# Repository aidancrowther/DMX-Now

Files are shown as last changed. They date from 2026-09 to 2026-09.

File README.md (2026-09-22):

# DMX Now

DMX Now is an ESP8266-based DMX512 system. A host daemon accepts DMX from
Art-Net or an ENTTEC-compatible serial client, sends the latest complete
universe to a wireless transmitter, and distributes it over QuickESPNow to any
number of battery-powered receivers. Each receiver regenerates DMX512 through
an RS-485 transceiver.

```text
Lighting software -> host daemon -> ESP8266 transmitter
                                      |
                                      +-- QuickESPNow --> one or more receivers
                                                           |
                                                           +--> DMX512 fixtures
```

## Supported operating modes

The project supports the following operating modes and hardware roles.

### 1. Host bridge mode — normal production operation

The Linux host daemon accepts a DMX universe from one of its configured inputs,
the integrated ESP8266 transmitter broadcasts it over QuickESPNow, and one or
more ESP8266 receivers regenerate DMX512 for fixtures.

```text
Host input -> Linux daemon -> ESP8266 transmitter
                              |
                              +-- QuickESPNow -> ESP8266 receiver(s) -> DMX512
```

The validated native/integrated transmitter target is 20 Hz:

```text
Wireless refresh:   20 Hz
Host transmitter:   115200 baud, 8N2
Universe:            512 channels
Wireless transport: QuickESPNow / ESP-NOW
Receiver output:    DMX512, 250000 baud, 8N2
```

The host can receive DMX through an ENTTEC-compatible serial PTY, Art-Net
ArtDMX, or an optional raw-DMX virtual PTY. The daemon also provides the
terminal dashboard, receiver management, priority traffic, channel gates, and
fail-safe configuration.

### 2. Management-only mode

The daemon and integrated transmitter can run without emitting ordinary DMX.
This mode is intended for a deployment where another device owns normal DMX,
especially the standalone physical-DMX retransmitter below. Telemetry,
receiver discovery, fail-safe settings, output control, locate, channel gates,
and explicit priority traffic remain available.

Start the daemon with either:

```bash
wireless-dmx run --management-only --config configs/config.example.toml
# or set [daemon] mode = "management_only" in the configuration
```

The integrated transmitter can also be built as a locked management-only image
with `./Helpers/flash_transmitter.sh --lock-management-only`.

In management-only mode, the transmitter passively listens for the standalone
retransmitter's ordinary ESP-NOW fragments and periodically reports the latest
complete universe to the daemon. The dashboard displays this read-only,
best-effort observed universe for operator feedback; it is not required for
retransmission or receiver operation. The transmitter keeps a local fallback for
its own priority transmissions because it cannot receive its own broadcast. When
a channel is changed to `LOCKED`, its current observed value is captured and
later retransmitter updates cannot replace it.

### 3. Standalone physical-DMX retransmitter

The standalone ESP8266 retransmitter receives physical DMX through a
receive-only RS-485 interface on UART0/GPIO3 and broadcasts the existing normal
three-fragment wireless protocol directly to the receivers. It does not require
the Linux daemon, a host transmitter, or a management transmitter for normal
operation.

Its production target is 10 Hz. It accepts complete and supported partial
physical-DMX frames from 24 through 512 slots, zero-filling the remaining
channels through channel 512. The retransmitter never drives its physical DMX
input line and has diagnostics disabled in the production image.

```text
Physical DMX source -> receive-only RS-485 -> ESP8266 retransmitter
                                               |
                                               +-- ESP-NOW -> receiver(s) -> fixtures
```

See [`Docs/retransmitter-deployment.md`](Docs/retransmitter-deployment.md) for
wiring, production flashing, radio configuration, recovery, and validation.

The retransmitter's production GPIO allocation keeps GPIO2 assigned to the
locate indicator (`LED_BUILTIN`). DMX input is receive-only and is not remotely
gated through GPIO2. Optional battery monitoring uses GPIO1 while DMXUART runs
in `SERIAL_RX_ONLY` mode. The production image with battery monitoring enabled
is built and flashed with:

```bash
./Helpers/flash_retransmitter.sh --production --battery-monitor -f \
  --port <RETRANSMITTER_PROGRAMMER_PORT>
```

### 4. Monitored retransmitter deployment

The retransmitter can be paired with a separate locked management-only ESP8266
transmitter. The physical retransmitter remains the sole normal-DMX authority;
the management transmitter provides receiver telemetry and control only. This
mode supports remote fail-safe configuration, receiver output control, locate,
channel gates, and explicit priority operations without creating a competing
ordinary-DMX source.

### 5. Arduino Mega USB-controlled DMX controller using `DMXSerial`

`Tests/mega_dmx_controller/` provides a simple local DMX source for bench
testing. It uses the `DMXSerial` library on Mega USART1, with DMX output on pin
18 and the USB connection available on `/dev/ttyUSB1` at 115200 baud, 8N1.

Flash it with:

```bash
./Helpers/flash_mega_dmx_controller.sh -f --port /dev/ttyUSB1
```

Enter newline-terminated commands over USB:

```text
<channel 1-512> <value 0-255>
1 255
24 128
clear
status
help
```

### 6. Arduino Mega USB-controlled DMX controller using `DmxSimple`

`Tests/mega_dmxsimple_controller/` is the equivalent local controller using
the `DmxSimple` library. Unlike the `DMXSerial` variant, it outputs DMX through
Mega digital pin 3 and does not use USART1. The USB command interface is still
available at 115200 baud, 8N1.

Flash it with:

```bash
./Helpers/flash_mega_dmxsimple_controller.sh -f --port /dev/ttyUSB1
```

It accepts the same `channel value`, `clear`, `status`, and `help` commands.

### Wireless transport behavior

The wireless transport is latest-state based. A receiver retains its last
complete universe when a fragment or wireless update is missed; incomplete
universes are discarded rather than promoted. The retransmitter and native
transmitter use the same shared packet protocol.

## Functions

- Receives DMX through ENTTEC-compatible serial input, Art-Net ArtDMX, or an
  optional raw-DMX virtual serial input accepting complete 512-byte universes.
- Expires incomplete raw-DMX bursts after 1 second without changing the active
  universe.
- Paces native/integrated wireless transmission at the validated 20 Hz rate and
  standalone retransmission at the validated 10 Hz rate.
- Reconstructs fragmented 512-channel universes safely on receivers using
  staging and active buffers; incomplete data is never promoted.
- Retains the last complete universe through temporary wireless loss and
  automatically recovers when a new valid universe arrives.
- Reports receiver telemetry including link freshness, battery, RSSI, sequence,
  counters, firmware, and fail-safe state.
- Delivers targeted priority complete universes with bounded retries and ACKs.
- Supports runtime channel gates: `OPEN`, `MANAGEMENT_ONLY`, and `LOCKED`.
- Supports receiver fail-safe modes:
  - `hold`: retain the last complete universe;
  - `blackout`: output a zero universe after the timeout;
  - `disable_line`: disable the RS-485 driver after the timeout.
- Provides receiver output enable/disable control and a temporary locate function
  for identifying hardware.
- Provides persistent receiver friendly names in the host configuration.
- Provides a Linux PTY input path and terminal dashboard with manual universe
  editing, normal/priority transmission, channel gates, receiver selection,
  output control, locate, telemetry, and validation actions.
- In management-only mode, optionally displays a best-effort observed universe
  reconstructed by the management transmitter from the standalone retransmitter;
  this is read-only QoL telemetry and is not required for operation.
- Converts physical DMX to the normal wireless protocol in standalone
  retransmitter mode, including partial-frame zero-fill through channel 512.
- Provides two simple Mega bench controllers that set individual channels over
  USB and continuously transmit a 512-channel DMX universe.

## Repository layout

```text
Firmware/Receiver/                  ESP8266 receiver firmware
Firmware/Transmitter/               ESP8266 transmitter firmware
Firmware/ReTransmitter/             UART0 physical DMX -> normal ESP-NOW firmware
Libraries/                           pinned project and third-party libraries
Host Software/wireless_dmx_daemon/   Linux/macOS host daemon and tests
Tests/                               firmware and hardware monitor sketches
Helpers/                             compile/flash helpers
Docs/                                detailed architecture, protocol, and validation docs
Hardware/                            PCB, schematic, enclosure, and manufacturing assets
DEVELOPMENT_PROGRESS.md   development history and status
```

## Hardware

Each receiver uses an ESP-01/ESP8266, MAX3485 RS-485 transceiver, battery
power/charging circuitry, and an external low-battery comparator. The receiver
uses GPIO1 for DMX TX, GPIO2 for inverted MAX3485 driver enable, and GPIO3 for
the active-high low-battery signal. See `Docs/hardware.md` and the schematic in
`Hardware/PCB Files/1-Schematic_ESP DMX.json`.

## Bundled libraries and pinned versions

DMX Now ships with the following bundled libraries. Use these project copies for
reproducible builds rather than substituting similarly named Arduino Library
Manager packages.

| Library | Role | Upstream | Declared version | Exact project pin |
|---|---|---|---:|---|
| [QuickESPNow fork](https://github.com/aidancrowther/QuickESPNow) ([upstream](https://github.com/gmag11/QuickESPNow)) | ESP-NOW transport | `Libraries/QuickESPNow/` | `0.8.1` | `27f88ad99e4b58958934c3a3dfabd62ccd338c62` |
| [espDMX fork](https://github.com/aidancrowther/espDMX) ([upstream](https://github.com/mtongnz/espDMX)) | ESP8266 physical DMX output | `Libraries/espDMX/` | v2 | `608ce009edfeebc3bca44b184a9dc667de055284` |
| [DMXUART](https://github.com/casesolved-co-uk/DMXUART) | Physical-DMX UART input/output | `Libraries/DMXUART/` | `4.0.3` | Bundled project copy |
| WirelessDMX | Project-owned wireless/management protocol | `Libraries/WirelessDMX/` | `1.0.0` | Matching DMX Now source |

For now, the DMX Now build points at the `aidancrowther` forks of QuickESPNow
and espDMX so the local changes remain available for pull requests and long-term
preservation. The original maintainer repositories are retained as upstream
references. QuickESPNow includes three project-specific commits beyond upstream,
and espDMX includes one. The exact commit pins above are authoritative.
QuickESPNow is MIT licensed, espDMX is GPL-3.0, and DMXUART is MIT licensed;
complete license texts are retained beside the bundled sources. `LXESP8266DMX`
was an unused former dependency and has been intentionally removed.

## Build and flash

The project uses `arduino-cli`, not PlatformIO:

```bash
./Helpers/flash_transmitter.sh
./Helpers/flash_receiver.sh
./Helpers/flash_retransmitter.sh
```

The normal transmitter helper defaults to bridge mode. Build the optional
management-only role with `./Helpers/flash_transmitter.sh --management-only`.
The daemon defaults to bridge mode; use `[daemon] mode = "management_only"` or
`wireless-dmx run --management-only` for management-only operation. The
management role never emits ordinary DMX, but priority/gate transactions remain
available.

The manual editor remains available in management-only mode and sends priority
traffic. Management edits may explicitly change locked channels. A lock only
blocks ordinary source/retransmitter updates; entering a lock captures the value
currently shown by the observer. Use the manual editor's `l` key to cycle gates.

Add `-f --port <device>` to flash a selected board. The helpers support
`--define` for compile-time test settings. Never leave a test-only transmitter
or receiver define enabled in a production image.

For physical retransmitter wiring, deployment roles, optional management-only
monitoring, and production/test image recovery, see
[`Docs/retransmitter-deployment.md`](Docs/retransmitter-deployment.md).

The reflashed production retransmitter was smoke-tested with a live Mega DMX
source and diagnostic receiver: 356 valid normal-DMX records were observed,
sequences advanced from 12 through 370, retransmitter input frames increased
from 0 to 253, wireless frames increased from 0 to 252, and wireless send
failures remained at 0.

## Host daemon

```bash
cd "Host Software/wireless_dmx_daemon"
python3 -m pip install .
wireless-dmx run --config configs/config.example.toml
```

The daemon prints the Linux PTY path. Configure a serial-capable application to
use that path, or use Art-Net Universe 0 over UDP port 6454. The complete daemon
configuration is documented in `Docs/daemon.md` and demonstrated in
`Host Software/wireless_dmx_daemon/configs/config.example.toml`.

Dashboard configurations are stored under `Host Software/wireless_dmx_daemon/configs/`. The
dashboard can select a configuration interactively when launched without
`--config`. The CLI and scripted dashboard forms continue to accept
`--config <path>`.

The optional raw-DMX input creates a second PTY and accepts one complete
512-byte universe per burst. Configure it under `[raw_virtual_port]` and select
it with `[input] source_policy = "raw_serial"`; incomplete bursts expire after
1 second by default.

## Receiver fail-safe configuration

```toml
[receiver_failsafe]
mode = "hold"          # hold, blackout, or disable_line
timeout_seconds = 60   # validated range: 30..3600
```

Settings are sent at runtime and are not persisted in receiver flash. Receivers
start with compile-time defaults and the daemon reapplies its configured
generation after startup, transmitter reconnect, receiver discovery, or
receiver reboot. Detailed semantics and finite validation procedures are in
`Docs/receiver-failsafe.md`.

## Tests

Run the host suite with:

```bash
cd "Host Software/wireless_dmx_daemon"
python3 -m pytest -q
```

The detailed test catalogue is in `Docs/testing.md`. Hardware-specific results
are kept separately in `Docs/lab-validation.md`; they are evidence for one
validated setup, not a requirement that every deployment have the same number
of receivers, USB paths, or monitor hardware.

The dashboard hotkey reference is in `Docs/daemon.md`.

## Limitations

- The current virtual serial backend targets Linux.
- Applications that only enumerate physical USB DMX interfaces may not list a
  Linux PTY; use Art-Net in that situation.
- Wireless rates above 20 Hz are experimental and not production-validated.
- ESP-NOW is unencrypted in the current QuickESPNow configuration.
- Receiver charging and DMX equipment require the isolation precautions in the
  hardware documentation.

## Project note

This is a vibe-coded project: AI-assisted development was used extensively for
implementation, documentation, and validation support. The hardware design,
wiring, and physical engineering decisions were managed by me.

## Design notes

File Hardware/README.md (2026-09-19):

# Hardware assets

This directory contains the physical design assets for DMX Now receivers and
related hardware.

## Contents

- `3D Models/` — enclosure and mechanical parts used to design and manufacture
  receiver housings. The current models are provided as `.3mf` files and are
  grouped under `3D Models/Receiver Enclosure/`.
- `PCB Files/` — PCB design exports, including the receiver schematic and board
  layout JSON files.

The electrical wiring, GPIO assignments, power precautions, RS-485 topology,
and isolation limitations are documented in [`../Docs/hardware.md`](../Docs/hardware.md).
The firmware and hardware roles are deployment-specific; inspect the schematic
and verify the actual assembled hardware before applying power.

## Current board-design assumptions

The current hardware layouts are intentionally limited to the following board
variants:

- **Receiver:** the receiver PCB layout currently supports only an ESP-01 or
  ESP-01S module.
- **Retransmitter:** the retransmitter PCB design, which has not yet been
  uploaded to this repository, currently supports only a WEMOS Mini Pro. This
  board choice is associated with the retransmitter's external antenna
  requirement.
- **Transmitter:** there is currently no dedicated transmitter PCB design. A
  supported ESP module connected directly through USB provides the required
  transmitter hardware.

Additional board variants may be added in the future, but none are currently
planned. Do not assume that a different ESP8266 module or board form factor is
electrically or mechanically interchangeable without a separate design review.

## Bill of Materials (B.O.M.)

> TODO: Populate and validate the production bill of materials before the first
> hardware release.

| Quantity | Reference / function | Part | Manufacturer | Manufacturer part number | Package | Supplier | Supplier SKU | Notes |
|---:|---|---|---|---|---|---|---|---|
| — | — | — | — | — | — | — | — | To be populated |

The B.O.M. should eventually include electrical components, connectors,
mechanical hardware, enclosure parts, cables, battery/power components, and
approved substitutions.

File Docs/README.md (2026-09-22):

# Documentation

The root README is deployment-neutral. These guides contain detailed system,
protocol, hardware, fail-safe, and testing information.

- `architecture.md` — data flow and component responsibilities.
- `daemon.md` — host daemon, configuration, PTY, telemetry, and dashboard.
- Receiver and retransmitter aliases are edited from the dashboard with `n` and
  persisted under `[receiver_names]` in the active TOML configuration.
- `protocol.md` — DMX, priority, management, telemetry, and ACK formats.
- `management-interface.md` — detailed host/transmitter/receiver/retransmitter
  control-plane guide with packet flow diagram.
- `build-flags.md` — firmware compile-time options and test hooks.
- `receiver-failsafe.md` — fail-safe modes, timing, configuration, and recovery.
- `hardware.md` — receiver electronics, pins, power, and programming.
- `retransmitter-deployment.md` — standalone and management-monitored physical-DMX retransmitter deployment.
- `testing.md` — automated, raw-DMX timeout, and generic hardware validation procedures.
- `lab-validation.md` — setup-specific qualification evidence, including the
  completed production retransmitter and 10 Hz extended validation.
- `priority-packet-substantial-completion.md` — priority/gating completion record.

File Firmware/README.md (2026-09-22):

# Firmware

This directory contains the production ESP8266 firmware roles for DMX Now.

## Roles

- `Receiver/` — receives QuickESPNow fragments and regenerates physical DMX512.
- `Transmitter/` — host-connected integrated transmitter with ENTTEC input,
  telemetry, management, priority traffic, and optional management-only
  observed-universe support.
- `ReTransmitter/` — receives physical DMX through a receive-only RS-485 input
  and rebroadcasts the normal three-fragment wireless protocol. Production builds
  also publish best-effort retransmitter telemetry; `--telemetry-only` is a
  diagnostic scheduler variant and is not a deployment image.

The native/integrated transmitter production target is 20 Hz. The standalone
physical-DMX retransmitter production target is 10 Hz.

Build and flash from the repository root with the helpers in `../Helpers/`:

```bash
./Helpers/flash_receiver.sh
./Helpers/flash_transmitter.sh
./Helpers/flash_retransmitter.sh
```

Compilation is the default. Add `-f --port <device>` only after confirming the
target board and serial adapter. Diagnostic and fault-injection images are not
production images and must be replaced before fixture use.

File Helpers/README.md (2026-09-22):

# Build and flash helpers

The scripts in this directory compile or flash firmware and hardware test
sketches using `arduino-cli`. They are intended to be run from the repository
root, although each script derives its own absolute project root.

## Production firmware

```bash
./Helpers/flash_transmitter.sh
./Helpers/flash_receiver.sh
./Helpers/flash_retransmitter.sh
```

Helpers compile by default. Add `-f --port <device>` to flash a selected board.
The transmitter helper supports `--management-only`, `--lock-management-only`,
`--lock-bridge`, and `--d1`. The retransmitter helper supports `--production`,
`--telemetry-only`, `--d1`, channel, universe, rate, menu configuration, and extra
compiler definitions. It also supports optional battery monitoring with
`--battery-monitor` and `--battery-low-active-high`. Production retransmitter
builds include telemetry; the telemetry-only option is for scheduler/control
testing and disables DMX input and normal retransmission. GPIO2 remains the
retransmitter locate indicator; there is no production GPIO2 DMX input gate.

## Bench and diagnostic sketches

The remaining helpers target the sketches under `../Tests/`, including ESP-NOW
checks, Mega DMX controllers/monitors, the Pico monitor, GPIO diagnostics, and
the retransmitter end-to-end Mega harness. Refer to `../Docs/testing.md` before
running a hardware test.

Diagnostic and fault-injection builds are compile/test images. Always restore a
production image after testing and confirm the target serial port before using
`-f`.

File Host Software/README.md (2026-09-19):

# Host software

The host-side software is under
[`wireless_dmx_daemon/`](wireless_dmx_daemon/). It is a Python package providing
the DMX bridge, management service, virtual serial backends, Art-Net input,
telemetry, priority control, and terminal dashboard.

Start from the repository root with:

```bash
cd "Host Software/wireless_dmx_daemon"
python3 -m pip install .
wireless-dmx-dashboard --config configs/default.conf
```

See the package README and `../Docs/daemon.md` for Linux/macOS operation,
systemd, LaunchAgent, configuration, and dashboard details.

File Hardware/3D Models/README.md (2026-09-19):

# 3D models

Mechanical models for DMX Now enclosure parts are stored here. The current
receiver enclosure models are under `Receiver Enclosure/` and are provided as
`.3mf` files for slicing, inspection, and mechanical revision work.

Confirm fit, wall thickness, connector clearances, and print orientation against
the current assembled hardware before manufacturing.

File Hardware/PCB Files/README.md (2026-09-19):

# PCB files

This directory contains PCB design exports for the DMX Now receiver hardware:

- `1-Schematic_ESP DMX.json` — electrical schematic export.
- `1-PCB_PCB_ESP DMX.json` — PCB/layout export.

These files are design inputs/exports rather than a substitute for a fabrication
release package. Verify revision, design-rule status, footprints, drill data,
and manufacturing outputs before ordering boards.

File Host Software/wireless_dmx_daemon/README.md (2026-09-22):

# DMX Now Host Daemon

This directory contains the host-side bridge for the DMX Now ESP8266 system
system. The daemon will expose a virtual ENTTEC-compatible serial port to
lighting software, forward validated DMX data to the ESP8266 transmitter at
115200 8N2, pace DMX frames at the validated 20 Hz wireless rate, and expose
receiver telemetry and operating statistics through a CLI and future GUI/API.

## Project attribution

This host software is vibe coded with AI assistance. The underlying Wireless
DMX hardware was designed by me.

## Initial assumptions

* Supported host platforms: Linux and macOS.
* Virtual serial uses a host-selected POSIX PTY backend for ENTTEC-compatible
  and optional raw-DMX input. Linux uses `LinuxPtyBackend`; macOS uses
  `MacOSPtyBackend`. Art-Net is available as an equivalent network input.
* Transmitter connection: configurable serial device, default `/dev/ttyUSB0`.
* Transmitter serial format: 115200 baud, 8 data bits, no parity, 2 stop bits.
* Default wireless pacing rate: 20 Hz.
* Art-Net ArtDMX input is enabled by default on UDP port 6454, Universe 0.
* ENTTEC serial, raw-DMX serial, and Art-Net inputs can be enabled independently
  or together.
* Rates above 20 Hz require an explicit experimental override.
* Telemetry is binary management traffic. The transmitter's text
  telemetry logging is not enabled during normal operation because it would
  corrupt the shared ENTTEC/management UART.

For macOS LaunchAgent installation, see `macos/README.md` and
`macos/install_launch_agent.py`. macOS serial devices are normally exposed as
`/dev/cu.*` paths.

## Running the daemon

The daemon has two host-side roles:

* **Bridge mode** (the default) starts the configured ENTTEC PTY, optional raw
  DMX PTY, and Art-Net input, then sends ordinary DMX through the transmitter.
* **Management-only mode** does not start ordinary DMX inputs and rejects
  normal DMX transmission. It retains receiver telemetry, discovery, fail-safe
  configuration, output control, locate, channel gates, and explicit priority
  traffic. It also polls an optional best-effort observed universe reconstructed
  by the management transmitter from the standalone physical-DMX retransmitter.
  Use this role when a standalone physical-DMX retransmitter owns the normal DMX
  source.

The role can be selected in the configuration:

```toml
[daemon]
mode = "management_only" # bridge or management_only
```

The command-line flags override the configured role for one invocation:

```bash
wireless-dmx run --config configs/default.conf
wireless-dmx run --management-only --config configs/default.conf
wireless-dmx run --bridge-mode --config configs/default.conf
```

The interactive management dashboard is usually the preferred operator
interface. It owns one in-process daemon and exposes receiver and retransmitter
telemetry, persistent names, fail-safe settings, receiver output control, locate,
channel gates, manual/priority
operations, and status panels:

```bash
wireless-dmx-dashboard --config configs/default.conf
wireless-dmx-dashboard --management-only --config configs/default.conf
```

Do not start a separate `wireless-dmx run` process at the same time as the
dashboard using the same transmitter and PTY paths. The dashboard starts and
stops its own service.

In management-only mode, the manual-universe view displays the latest complete
observed retransmitter universe when available. It is read-only/best-effort and
becomes stale when observation reports stop. Locally sent priority values provide
the fallback until a retransmitter observation arrives. Observed values are never
submitted to the pacer.

Receiver and retransmitter records are kept in separate caches. Retransmitters are
discovered from response opcode `0x8B` and show freshness, always-enabled DMX
input state, physical-DMX source age, learned slot count, wireless counters,
locate state, and battery state. Only actively reporting retransmitters populate
this cache and dashboard; inactive entries are removed rather than retained as
stale inventory. Battery reports `UNKNOWN` when monitoring is not compiled in,
or `OK`/`LOW` when the optional comparator support is enabled. Aliases are
persisted under `[receiver_names]` while stable hardware IDs remain visible.
Retransmitter locate requests use the priority management path and are confirmed
by later telemetry, not enqueue success alone. Retransmitter input
enable/disable is not part of the production hardware contract.

### Linux foreground launch

From this directory, install the package into the active Python environment and
run the selected role in the foreground:

```bash
python3 -m pip install .
wireless-dmx run --management-only --config configs/default.conf
```

The command prints the generated ENTTEC PTY path in bridge mode. Art-Net input
continues to use UDP port 6454 and does not require a PTY client.

### Linux systemd launch

The repository provides `systemd/wireless-dmx.service`. It is a system-level
template that expects the installed command at `/usr/bin/wireless-dmx`, the
daemon working directory at `/opt/wireless-dmx-daemon`, and configuration at
`/etc/wireless-dmx/config.toml`. Adjust those paths if the package is installed
elsewhere.

```bash
sudo install -D -m 0644 systemd/wireless-dmx.service \
  /etc/systemd/system/wireless-dmx.service
sudo systemctl daemon-reload
sudo systemctl enable --now wireless-dmx.service
sudo systemctl status wireless-dmx.service
sudo journalctl -u wireless-dmx.service -f
```

For a management-only service, set this in the service's configuration file
before starting or restarting it:

```toml
[daemon]
mode = "management_only"
```

Then apply the change:

```bash
sudo systemctl restart wireless-dmx.service
```

Stop and disable the service with:

```bash
sudo systemctl disable --now wireless-dmx.service
```

The systemd unit itself does not add `--management-only`; the role comes from
the selected TOML configuration. This keeps bridge and management-only launch
behavior identical across Linux and macOS.

### macOS foreground launch

Use a `/dev/cu.*` transmitter device in the selected configuration, then run:

```bash
python3 -m pip install .
wireless-dmx run --management-only --config configs/default.conf
```

Or launch the dashboard directly:

```bash
wireless-dmx-dashboard --management-only --config configs/default.conf
```

### macOS LaunchAgent launch

The installer in `macos/install_launch_agent.py` generates a per-user
LaunchAgent using the current Python interpreter. Select the role in the TOML
file used by the agent, then install and load it:

```bash
python3 macos/install_launch_agent.py \
  --config "$(pwd)/configs/default.conf"
launchctl bootstrap "gui/$(id -u)" \
  "$HOME/Library/LaunchAgents/com.dmxnow.daemon.plist"
```

Before installing, edit the selected configuration so it contains the desired
role and macOS transmitter device, for example:

```toml
[daemon]
mode = "management_only"

[transmitter]
device = "/dev/cu.YOUR_TRANSMITTER_ADAPTER"
```

Use `launchctl print` to inspect the running agent and `launchctl bootout` to
stop it. Full paths, logs, and lifecycle commands are documented in
`macos/README.md`. The LaunchAgent runs the daemon directly; use the dashboard
as a separate interactive management client only when it is not also starting
another daemon process for the same transmitter.

## Architecture

```text
CLI / future GUI
        |
Application service and state snapshots
        |
  +-----+----------+----------------+
  |                |                |
PTY backend    ENTTEC parser    Telemetry store
  |                |                |
  +----------> DMX pacer <-------+
                    |
           Transmitter connection
                    |
             ESP8266 transmitter
```

Core code must not depend directly on terminal presentation, operating-system
PTY details, or a particular serial library. Those concerns belong in adapter
modules.

## Phased implementation plan

### Protocol and architecture contract

Create the package structure, core dataclasses, configuration model, protocol
contracts, and service-state snapshots. Add dependency-free tests for these
interfaces. No live serial or OS-specific behavior is required.

**Completion criteria:** package imports cleanly; public interfaces are
documented; models are immutable where appropriate; unit tests cover defaults,
validation, receiver state calculation, and statistics; future CLI/GUI code can
consume a service snapshot without accessing I/O objects.

### ENTTEC protocol parser and statistics

Implement a streaming parser supporting partial reads, concatenated frames,
embedded delimiter bytes, valid short/full universes, malformed lengths,
unsupported labels, and recovery after corruption. Track input and rejection
statistics.

**Completion criteria:** parser cases pass as host tests;
valid frames produce one normalized DMX universe; malformed input cannot alter
the active universe.

### Transmitter serial connection

Implement configurable 115200 8N2 serial I/O, bounded read/write behavior,
reconnection, timeouts, clean shutdown, and a fake serial adapter for tests.

**Completion criteria:** `/dev/ttyUSB0` can be opened with the correct format;
serial failure recovery is tested without hardware; no unbounded write queue
exists.

### DMX pacer

Implement latest-state pacing. New input replaces an unsent pending frame;
obsolete frames are counted as dropped rather than queued. Make target rate,
limits, policy, and experimental override configurable.

**Completion criteria:** a 40 Hz input stream produces approximately 20 Hz
transmitter submissions by default; pacer statistics distinguish received,
submitted, and dropped frames.

### Virtual serial port

Implement the Linux PTY backend. Expose the slave path, optionally create a
safe configurable symlink, tolerate no client/client reconnect, and clean up on
shutdown. Keep OS-specific details behind a backend interface.

**Completion criteria:** a normal serial application can open the virtual port;
ENTTEC bytes reach the parser; client disconnects do not crash the daemon.

### Binary telemetry management

Implement telemetry requests, CRC validation, multipart report grouping,
receiver storage, freshness states, retries, and background scheduling.

**Completion criteria:** one and multiple receivers are decoded; multipart
responses work; malformed/old reports are rejected; telemetry never blocks DMX
pacing.

### CLI interface

Add `run`, `status`, `receivers`, `stats`, `config-check`, and `version`
commands. The CLI renders service snapshots rather than owning business logic.

**Completion criteria:** current DMX and receiver state is visible; startup and
shutdown are clean; a future GUI can reuse the service layer.

### Configuration and persistence

Add TOML configuration, command-line overrides, validation, effective-config
display, and safe defaults.

**Completion criteria:** invalid device/rate/timeout settings fail before I/O;
CLI overrides take precedence over file values.

### Resilience and service operation

Add transmitter reconnect, PTY client reconnect, bounded backoff, signal
handling, health states, structured logs, and optional systemd integration.

**Completion criteria:** transmitter unplug/replug and daemon restart recover
without replaying stale DMX history.

### Hardware validation

Run the daemon with the real transmitter and Arduino Mega monitor. Validate
20 Hz operation, telemetry, malformed input recovery, receiver disappearance,
transmitter reset, and virtual-port reconnect behavior.

**Completion criteria:** more than ten minutes at 20 Hz with zero Mega DMX
pattern failures, no unexplained no-data gaps, valid telemetry, bounded memory,
and safe reconnect behavior.

## Current implementation status

The host status/management scope is complete for the validated Linux/20 Hz
deployment. The package has
standard-library core models, a streaming ENTTEC parser, binary management
codec, bounded latest-state pacer, reconnecting transmitter adapter, Linux PTY
backend, TOML loading, CLI entry point, structured logging, and a systemd unit
template. Reliability/throughput testing, hardware fail-safe refinement,
targeted priority transmission, and receiver hard gating are **COMPLETE for the
validated Linux/20 Hz hardware
configuration**: manual complete-universe sends,
bounded queueing, repeat/TTL handling, receiver ACKs, per-receiver
retry/recovery, lead-in/lead-out timing, receiver-side runtime hard locks, and
normal-stream resumption are implemented. The detailed priority completion
record is
`../../Docs/priority-packet-substantial-completion.md`.
The current hardware qualification covers dynamic receiver discovery, hard-gate
establishment/unlock, normal-packet blocking, normal resumption, receiver
removal/reconnection, transmitter reset recovery, daemon restart recovery, PTY
client disconnect/reconnection, priority soak, and all three receiver fail-safe
modes. Native Windows/macOS virtual serial support, broader platform/application
coverage, and a future GUI remain follow-up work.

The host implementation has passed the automated suite and live validation. The
live path opens the configured transmitter, exposes a Linux PTY, forwards full
ENTTEC universes, and receives telemetry from dynamically discovered receivers.
The existing ESP8266/Mega 660-second acceptance run remains the authoritative
physical DMX/RF evidence; the host daemon's live test confirms the additional
PTY, parser, pacing, transmitter-serial, and telemetry integration path.

### Reliability, fail-safe, and priority completion evidence

The final lab acceptance completed with 36,000 DMX frames submitted at 20 Hz
and 79,869/79,869 Mega checks passing. Priority events produced no failed,
retried, invalid, or unknown completions.

The hard-gate test passed lock and unlock transactions:

* all expected receivers reported `PRIORITY_COMPLETE_GATE_APPLIED`;
* both transactions succeeded on the first attempt with zero retries;
* normal traffic remained blocked at the locked priority value;
* normal output resumed after the unlock transaction;
* all Mega measurement windows had zero failures.

The priority soak produced 20/20 first-attempt successes, zero
failed events, zero retry recoveries, zero invalid/unknown ACKs, and zero retry
failures. The duplicate ACK records reported by the soak are expected repeated
physical completion records and did not affect event completion.

Hardware intervention coverage also passed: receiver removal/reconnection,
transmitter reset with the daemon running, daemon restart, and PTY client
disconnect/reconnection all recovered with valid normal DMX output. Receiver
fail-safe coverage passed `hold`, `blackout`, and `disable_line` with finite
Mega measurements and automatic recovery. See `../../Docs/lab-validation.md`.

The default command is:

```bash
python3 -m wireless_dmx run --config configs/config.example.toml
```

Dashboard configuration files live in `configs/`. Starting the dashboard without
`--config` uses the last writable configuration when available, or opens the
interactive configuration selector. The CLI still accepts `--config <path>`.

The printed PTY slave paths are the ports to configure in lighting software. The
daemon owns the physical transmitter at 115200 8N2 and exposes current state
through service snapshots rather than mixing diagnostic text into the ENTTEC
stream.

## Art-Net input

QLC+ can use its Art-Net output plugin to send Universe 0 to the daemon without
requiring a discoverable USB Enttec interface. The default Art-Net listener is:

```text
bind:     0.0.0.0
UDP port: 6454
Universe: 0
```

Configure QLC+ to send Art-Net to the daemon host's IP address and Universe 0.
The daemon normalizes ArtDMX payloads to 512 channels and sends them through the
same 20 Hz latest-state pacer used by the virtual serial input.

An optional second Linux PTY accepts raw DMX universes without ENTTEC framing:

```toml
[raw_virtual_port]
enabled = true
requested_path = "/tmp/wireless-dmx-raw"
timeout_seconds = 1.0

[input]
source_policy = "raw_serial"
```

Write one complete 512-byte universe per burst. The raw-DMX parser handles PTY
partial reads and concatenated bursts while preserving the same source gating
and pacer behavior as other inputs. Incomplete bursts expire after the configured
`timeout_seconds`, which defaults to 1.0 second.

Input combinations are configured in TOML:

```toml
[virtual_port]
enabled = true

[artnet]
enabled = true
bind_host = "0.0.0.0"
port = 6454
universe = 0

[input]
source_policy = "latest" # latest, serial, or artnet
```

Use `source_policy = "serial"` or `"artnet"` to give one input source
exclusive ownership when both are enabled. `latest` accepts whichever valid
source frame arrives most recently.

If no configuration path is supplied, the application loads
`default.conf` from its working directory when present, otherwise it uses the
built-in safe defaults.

The dashboard treats `default.conf` as a read-only baseline. Start the dashboard
without `--config` to choose from available `.conf` and `.toml` files, or press
`c` while it is running to switch configurations. Use Save As in the setup
editor to create a writable configuration file. The `--config` option remains
available for CLI and scripted management.

The Art-Net listener is a UDP input adapter and does not require QLC+ to see a
USB or serial interface. Configure QLC+'s Art-Net output for the daemon host,
Universe 0, and UDP port 6454. The daemon accepts ArtDMX while virtual serial
is enabled, disabled, or used simultaneously. When both sources are enabled,
`input_source_policy = "latest"` accepts the most recent valid frame;
`"serial"` or `"artnet"` can enforce exclusive source ownership.

The end-to-end acceptance runner is intended for a host with a transmitter, a
physical DMX monitor, and the expected receivers online. It submits complete
universes at the configured rate, validates the physical monitor output, and
logs daemon telemetry/progress. Setup-specific evidence is documented in
`../../Docs/lab-validation.md`.

The end-to-end acceptance runner is:

```bash
python3 Tests/run_30min_acceptance.py \
  --tx-port <transmitter-device> \
  --mega-port <monitor-device> \
  --seconds 1800 \
  --run-dir runs/30min-acceptance
```

It opens the daemon PTY as a serial client, streams a complete ramp universe at
20 Hz, validates the physical receiver output with the Arduino Mega, and logs
daemon telemetry/progress. The transmitter's text telemetry logging must remain
disabled because its UART carries the ENTTEC stream.

For a one-shot live receiver query:

```bash
python3 -m wireless_dmx --config config.example.toml status
```

## btop-like management dashboard

The single wrapper application is the curses dashboard:

```bash
python3 wireless_dmx_dashboard.py --config config.example.toml --mega-port <monitor-device>
```

Start explicitly in bridge mode (the default behavior):

```bash
python3 wireless_dmx_dashboard.py --bridge-mode
```

Start with normal DMX bridging disabled while retaining transmitter management
and priority traffic:

```bash
python3 wireless_dmx_dashboard.py --management-only
```

These mode flags override the mode from the selected configuration for the
current invocation only. They are mutually exclusive.

or, after installing the package:

```bash
wireless-dmx-dashboard --config config.example.toml --mega-port <monitor-device>
```

The dashboard owns one in-process `WirelessDmxService`, so it is the preferred
interactive management entry point rather than starting the daemon separately.
It uses a btop-inspired continuously refreshed terminal layout with color-coded
health states, compact ASCII bar visualizations for DMX/pacer activity and RSSI,
and separate panels for daemon state, receiver telemetry, and recent events.

### Dashboard controls

| Key | Action |
|---|---|
| `d` | Start or stop the in-process daemon |
| `r` | Schedule an immediate telemetry request |
| `x` | Enter/leave the Advanced hardware-testing menu |
| `s` | Open the configuration setup editor |
| `l` | Toggle the event panel |
| `q` | Stop components and exit cleanly |

Mega testing and the acceptance runner are intentionally hidden behind the
Advanced menu (`x`) because they are development/validation functions rather
than normal release controls. Inside Advanced:

| Key | Action |
|---|---|
| `m` | Connect to the configured monitor and start a Mega measurement |
| `a` | Launch the external 30-minute acceptance runner |
| `b` | Abort the active Mega measurement |
| `x` | Return to the main dashboard |

The `a` action starts `Tests/run_30min_acceptance.py` as a bounded external
process and writes evidence to `runs/dashboard-acceptance/`. The dashboard
does not mix Mega monitor text or diagnostic output into the transmitter UART.
The daemon continues to use binary telemetry management traffic.

The dashboard/controller is separated from curses rendering. Future GUI code
can reuse `DashboardController`, `WirelessDmxService`, `DaemonSnapshot`, and
`MegaMonitorController` without depending on terminal drawing functions.

### Configuration setup editor

Press `s` on the main dashboard to edit the selected configuration fields,
including Art-Net enablement, bind host, UDP port, universe, and input policy.
Navigate with arrow keys or `j`/`k`, press `e` to edit a value, `w` to save
atomically, and `x` to cancel. The editor validates each change before applying
it and saves to the path selected by `--config-path` or the active configuration
path. Restart the daemon after changing settings that affect sockets, PTYs, or
the transmitter connection.

The complete hotkey reference for every dashboard view is in `../../Docs/daemon.md`
under “Dashboard hotkeys”. It includes manual priority feedback, repeat/TTL
controls, and zero-universe reset.

Manual DMX value entry uses a temporary blocking input mode so typed values are
accepted reliably even though the live dashboard normally uses non-blocking
keyboard polling. In the full-universe manual view, press `g` to switch between
the channel list and a 16-column hex-dump-style grid; the selected channel is
highlighted in either view.

In full-universe grid mode, the left/right arrows move horizontally by one
channel and the up/down arrows move by one 16-channel row. In list and channel
modes, left/right do nothing. Press `a` in any manual mode to jump directly to
channel 1–512.

In grid mode, type a value directly with the number keys and press Enter to
apply it to the selected channel. Values must be 0–255; Backspace removes a
digit. Enter with no typed value continues to send the complete universe.

## Suggested future layout

```text
Host Software/wireless_dmx_daemon/
├── README.md
├── pyproject.toml                 # introduced with packaging phase
├── wireless_dmx/
│   ├── __init__.py
│   ├── app.py
│   ├── cli.py
│   ├── config.py
│   ├── models.py
│   ├── pacer.py
│   ├── stats.py
│   ├── telemetry.py
│   ├── enttec/
│   │   ├── __init__.py
│   │   ├── parser.py
│   │   └── protocol.py
│   ├── Firmware/Transmitter/
│   │   ├── __init__.py
│   │   ├── connection.py
│   │   └── management.py
│   └── virtual_serial/
│       ├── __init__.py
│       ├── base.py
│       └── linux_pty.py
└── Tests/
```

## Development rules

* Keep all temporary files inside this project directory.
* Prefer standard-library interfaces in the foundational implementation.
* Keep I/O adapters replaceable and testable with fakes.
* Use fixed/bounded queues and latest-state semantics.
* Do not enable transmitter text telemetry logging while forwarding ENTTEC
  traffic.
* Hardware verification must identify which behaviors were actually measured.

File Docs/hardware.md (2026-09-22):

# Hardware reference

Receivers use an ESP-01/ESP8266, MAX3485 RS-485 transceiver, battery
charging/protection and regulation, and comparator-based low-battery detection.

```text
GPIO1 / UART TX -> MAX3485 DI / DMX data
GPIO2           -> inverted MAX3485 DE control
GPIO3 / UART RX <- active-high low-battery comparator
GPIO0           -> ESP8266 boot/programming use
```

GPIO2 high disables the MAX3485 and GPIO2 low enables it. Firmware keeps the
line disabled during startup and enables it only when initialization and the
configured fail-safe policy permit output.

The current receiver design has no separate controllable status LED. The locate
implementation is therefore deliberately disruptive: it suspends espDMX,
releases GPIO1 from the UART mux, disables the MAX3485 initially, and pulses
both GPIO1 and GPIO2 with a 500 ms half-period for 15 seconds. Driving both
pins accommodates ESP-01 boards whose onboard LED is wired to either commonly
used LED GPIO. GPIO2 is also the MAX3485 enable line, so the pulse pattern
intentionally toggles the RS-485 driver; disconnect the receiver from DMX
fixtures before locating. A future board revision with a dedicated LED GPIO
could provide a non-disruptive locator.

The current design does not provide galvanic USB/DMX isolation. Disconnect a
receiver from DMX equipment before connecting USB charging power. The full
schematic is `Hardware/PCB Files/1-Schematic_ESP DMX.json`.

Receiver modules are programmed separately with:

```bash
./Helpers/flash_receiver.sh -f --port <programmer-device>
```

Identify receivers by telemetry identity, not by an assumed USB device number.

For re-transmitter testing, a diagnostic receiver image can be built with
`./Helpers/flash_receiver.sh --diagnostic`. That image does not initialize
espDMX and keeps the MAX3485 output disabled. It sends complete reconstructed
universes as binary `RDX1` records over UART0/GPIO1 at 115200 8N1, allowing the
USB programmer/serial adapter to be used as a logical DMX observation port.
Each diagnostic record also includes the six-byte ESP-NOW source MAC for the
promoted fragment sequence, before the 512 channel bytes. This permits tests to
distinguish the intended physical retransmitter from another normal-DMX source
within radio range.
The diagnostic image is a test role and must be replaced with the production
receiver image before normal fixture output is used.

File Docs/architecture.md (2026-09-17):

# System architecture

```text
Art-Net / ENTTEC client -> Linux daemon -> ESP8266 transmitter
                                                |
                                      QuickESPNow wireless transport
                                                |
                                      one or more receivers -> DMX512

An optional management-only transmitter can share the wireless channel with a
standalone physical-DMX re-transmitter. In that deployment the re-transmitter
is the sole source of normal DMX fragments. The management transmitter sends
telemetry/control traffic and explicit priority DMX only; it never emits normal
DMX fragments. The re-transmitter has no host-management dependency and may
continue operating while the management transmitter is offline.
```

The daemon accepts Art-Net or ENTTEC-compatible serial input, normalizes it to
512 channels, and uses bounded latest-state pacing. The transmitter snapshots a
complete universe before fragmentation. Receivers promote only complete,
structurally valid frames and retain the last active universe when fragments or
wireless updates are lost.

In management-only/retransmitter deployments, the management transmitter also
passively receives ordinary DMX fragments on the shared ESP-NOW channel. It
reconstructs complete observations in loop context and exports them as bounded
multipart management responses at a low polling rate. This observer is optional,
read-only, and non-authoritative; it cannot receive its own broadcasts, so locally
sent priority universes provide the display fallback. The daemon preserves local
values on hard-locked channels when applying retransmitter observations.

Priority traffic has separate pacing, targeting, bounded retries, completion
ACKs, and optional atomic channel-gate metadata. Management traffic uses
CRC-protected binary frames on the transmitter UART and bounded multipart
telemetry reports.

Failure boundaries are deliberate: invalid input is rejected, incomplete frames
are abandoned, stale frames cannot regress active output, transmitter loss is
handled by receiver fail-safe policy, and PTY clients may disconnect without
stopping the daemon.

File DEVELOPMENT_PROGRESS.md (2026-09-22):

# DMX Now

Experimental wireless DMX512 system using ESP8266 modules, QuickESPNow, and MAX3485 RS-485 transceivers.

The system uses a PC-connected ESP8266 transmitter to receive DMX universe data and broadcast it wirelessly to multiple battery-powered ESP-01 receivers. Each receiver maintains the last complete wireless universe and continuously regenerates a normal wired DMX512 signal for its attached fixture or DMX chain.

The project is being developed incrementally. For espDMX hardware output, compilation success implies hardware validation; for QuickESPNow wireless transport, compilation verification does not imply link budget or throughput validation.

## Core Design

The intended data path is:

```
PC lighting software
        |
        | ENTTEC DMX USB Pro-compatible serial protocol
        v
ESP8266 transmitter
        |
        | latest universe buffer
        |
        | configurable refresh rate
        v
QuickESPNow broadcast
        |
   +----+----+---------+
   |         |         |
   v         v         v
ESP-01    ESP-01    ESP-01
receiver  receiver  receiver
   |         |         |
MAX3485   MAX3485   MAX3485
   |         |         |
  DMX       DMX       DMX
   |         |         |
fixture   fixture   fixture
```

The wireless transport is intentionally a latest-state system rather than a guaranteed-delivery stream.

If a wireless update is missed, receivers continue outputting their previous complete universe until a newer complete universe arrives.

## Development Approach

Develop this project as a series of small, independently testable features.

Do not attempt to implement the entire system in one pass.

Each feature should:

1. Have a narrow scope.
2. Compile before moving on.
3. Avoid unrelated refactoring.
4. Preserve previously working functionality.
5. Clearly distinguish compile-tested behavior from hardware-tested behavior.
6. Leave TODO comments where hardware verification is required.

When working on a requested feature, stop when that feature is complete unless explicitly instructed to continue.

## Working Directory

All development work must remain within the current project directory.

Do not use `/tmp`, `/var/tmp`, or another external directory for drafting or development.

If temporary working files are required, use a local directory such as:

```
./.work/
```

or:

```
./tmp/
```

This allows development activity to be monitored while the coding agent is working.

## Toolchain

Use the Arduino ESP8266 framework.

Do not use PlatformIO.

Use `arduino-cli` for compilation verification.

ESP8266 Arduino board package:

```
http://arduino.esp8266.com/stable/package_esp8266com_index.json
```

Receiver board target:

```
esp8266:esp8266:generic
```

This corresponds to the Generic ESP8266 Module target and is suitable for the ESP-01.

Before adding board-specific FQBN options, inspect the installed options with:

```
arduino-cli board details -b esp8266:esp8266:generic
```

ESP-01 modules may have different flash capacities, so do not assume a particular flash-size option unless established for the hardware being used.

## Required Libraries

### QuickESPNow

Repository:

```
https://github.com/aidancrowther/QuickESPNow
```

QuickESPNow MUST be obtained from the DMX Now fork above for the current build.
The upstream repository is https://github.com/gmag11/QuickESPNow.

Do not install or substitute a version from Arduino Library Manager.

Preferred local location:

```
./Libraries/QuickESPNow/
```

The checked-out source should be inspected before using its API.

Record the Git commit used for development in this README once installed.

QuickESPNow is responsible for wireless communication between the transmitter and receivers.

The ESP8266 implementation is documented as providing approximately 200 kbps of practical throughput. Do not assume this bandwidth is guaranteed.

### espDMX

Repository:

```
https://github.com/aidancrowther/espDMX
```

espDMX MUST be obtained from the DMX Now fork above for the current build.
The upstream repository is https://github.com/mtongnz/espDMX.

Do not install or substitute a version from Arduino Library Manager.

Preferred local location:

```
./Libraries/espDMX/
```

espDMX is responsible for generating the physical DMX512 output from receiver ESP8266 modules.

Inspect the checked-out source and examples before using its API.

Record the Git commit used for development in this README once installed.

The espDMX library uses pre-declared global instances (`dmxA`, `dmxB`) — instantiate locally to avoid conflicts with the upstream globals (we use `dmxA` on UART0/GPIO1).

## Receiver Hardware

Each receiver is intended to contain:

* ESP-01 / ESP8266
* MAX3485 3.3 V RS-485 transceiver
* 1-cell Li-ion/LiPo battery
* TP4056 charging/protection module
* 3.3 V buck/boost regulator
* LM358 low-battery comparator
* LM385Z-1.2 voltage reference
* 10 kΩ trim pot for low-battery threshold
* 2N2222 transistor for MAX3485 driver-enable inversion
* DMX transient protection
* appropriate decoupling/bulk capacitance

ESP-01 modules are socketed and will be removed from the receiver for programming.

There is no requirement for in-circuit programming.

## Receiver Pin Allocation

The intended ESP-01 pin allocation is fixed unless a hardware issue requires changing it:

```
GPIO1 / UART TX -> DMX data / MAX3485 DI

GPIO2           -> MAX3485 DE control
                   through inverting 2N2222 stage

GPIO3 / UART RX <- digital low-battery signal

GPIO0           -> reserved for normal ESP8266
                   boot requirements
```

GPIO3 does not need to remain available for programming because the ESP-01 will be physically removed and programmed separately.

## MAX3485 Driver Enable

GPIO2 controls MAX3485 DE through an inverting 2N2222 stage.

Hardware behavior:

```
GPIO2 HIGH
    -> 2N2222 ON
    -> MAX3485 DE LOW
    -> DMX transmitter disabled

GPIO2 LOW
    -> 2N2222 OFF
    -> MAX3485 DE pulled HIGH
    -> DMX transmitter enabled
```

This is intentional.

GPIO2 must be HIGH for normal ESP8266 boot, so the hardware arrangement ensures that the MAX3485 remains disabled during ESP startup.

Firmware must not enable DMX output until initialization is complete.

## Battery System

Receivers are battery powered during operation.

Current design:

```
1S LiPo
   |
TP4056
charger/protection
   |
3.3 V buck/boost
   |
   +---- ESP-01
   |
   +---- MAX3485
   |
   +---- supporting circuitry
```

Charging isolation is NOT currently implemented.

Operational rule:

```
Disconnect the receiver from DMX equipment before connecting USB charging power.
```

Do not assume that disabling the buck/boost converter provides galvanic isolation from USB ground.

## Low-Battery Detection

Battery state is detected externally rather than using an ESP8266 ADC.

Components:

* LM385Z-1.2 reference
* LM358 comparator
* 10 kΩ trim pot

The LM385 reference is approximately:

```
1.235 V
```

A 10 kΩ resistor supplies the LM385 reference from VBAT.

The trim pot is connected across VBAT and ground. Its wiper provides the battery sense voltage to the LM358.

The trim pot is manually calibrated to the desired low-battery threshold, initially expected to be approximately:

```
3.5 V
```

GPIO behavior:

```
GPIO3 HIGH = battery LOW
GPIO3 LOW  = battery OK
```

Hardware hysteresis is intentionally omitted.

Software should filter the signal instead.

Suggested initial filtering:

```
HIGH continuously for ~2 seconds
    -> batteryLow = true

LOW continuously for ~5 seconds
    -> batteryLow = false
```

These timings are configurable in the receiver build with `BATTERY_LOW_ASSERT_MS`
and `BATTERY_LOW_CLEAR_MS`, whose defaults are 2000 ms and 5000 ms respectively.

The debounced `batteryLow` flag is retained for receiver telemetry. For the
Feature 9 hardware test build, asserting the flag causes the receiver to output
a universe of `0xFF` on all 512 channels; clearing it restores the latest
complete wireless universe. This test indication is intentionally implemented
without receiver Serial output because UART0 is owned by DMX.

## Wireless Architecture

Use QuickESPNow.

The transmitter broadcasts DMX state to all receivers.

Do not send the realtime DMX stream individually to each receiver.

Do not require per-receiver acknowledgements for realtime DMX data.

Conceptually:

```
               transmitter
                   |
              BROADCAST
              /   |   \
             /    |    \
           RX1   RX2   RX3 ...
```

This prevents communication overhead from scaling directly with receiver count.

## Wireless Refresh Rate

Wireless universe refresh rate and physical DMX refresh rate are separate concepts.

The validated production wireless refresh rate is:

```
WIRELESS_REFRESH_HZ = 20
```

This value must be configurable.

Feature 7 testing established approximately 20 Hz as the reliable production
ceiling for the ESP8266 RF link. Higher rates remain available for experiments
using `-DWIRELESS_REFRESH_HZ=N`; those rates are not the default reliability
target.

QuickESPNow's ESP8266 implementation has limited throughput, so do not assume full DMX refresh rates are practical over the wireless transport.

If PC updates arrive faster than the configured wireless refresh rate, retain
only the newest universe. ENTTEC-compatible converters may provide output at up
to approximately 40 Hz, so the transmitter UART has been increased to 115200
baud, 8N2. This provides enough serial bandwidth for the validated 20 Hz full-
universe wireless rate. A full 513-byte ENTTEC packet at 8N2 requires about
207200 baud at 40 Hz, so true 40 Hz full-universe input would require a higher
UART rate such as 230400; 40 Hz remains available as an experimental wireless
build override, not the validated production setting.

Example:

```
PC updates:          40 Hz
wireless refresh:    20 Hz
```

The transmitter should send approximately twenty snapshots of the latest
universe per second.

It should NOT queue the other 25 obsolete intermediate states.

## Wireless Packet Design

A complete 512-channel universe will need to be fragmented into multiple ESP-NOW packets.

The exact packet format should be established during the relevant feature implementation after inspecting QuickESPNow's actual payload limits/API.

Each fragment is expected to contain at least:

* protocol version
* packet type
* universe number
* frame/sequence number
* fragment index
* fragment count
* payload length
* channel payload

Use fixed-size data structures.

Avoid dynamic allocation in the realtime data path.

Include compile-time packet-size checks.

## Receiver Buffering

Receivers must never expose a partially received universe to the physical DMX output.

Use double buffering:

```
activeUniverse[512]
stagingUniverse[512]
```

Wireless fragments are written into the staging buffer.

Only after every fragment belonging to the same sequence has arrived may the completed universe replace the active universe.

Example:

```
Wireless frame 100 complete
    -> active = 100

Frame 101 missing fragment
    -> discard 101
    -> continue outputting 100

Frame 102 complete
    -> active = 102
```

This behavior is fundamental to the project.

## Physical DMX

Physical DMX generation is handled by espDMX.

The intended output is normal DMX512:

```
250000 baud
8 data bits
no parity
2 stop bits
valid BREAK
valid Mark After Break
start code 0
up to 512 channel slots
```

Physical DMX output continues independently of wireless updates.

For example:

```
wireless update = 1 Hz
physical DMX output = ~30 Hz
```

The receiver therefore repeatedly transmits its most recently completed universe even when no new wireless data has arrived.

The exact physical refresh behavior follows espDMX's intended API/implementation (interrupt-driven, self-refreshing at 44 Hz+).

## Receiver Startup Safety

The receiver must not output arbitrary UART/boot data onto DMX.

Expected startup sequence:

1. Keep MAX3485 DE disabled.
2. Initialize GPIO.
3. Initialize universe buffers.
4. Initialize QuickESPNow (if needed for this feature).
5. Initialize espDMX (`dmxA.begin()`).
6. Establish a valid initial universe (`dmxA.setChans()`).
7. Start controlled DMX operation.
8. Enable MAX3485 only when safe.

A future configuration option may determine whether the receiver:

* outputs a zero universe immediately after startup, or
* waits for its first valid wireless universe before enabling MAX3485.

## Transmitter

Initial transmitter hardware is simply:

```
PC
 |
USB
 |
USB/serial
 |
ESP8266
 |
QuickESPNow
```

No MAX3485 is required on the transmitter.

The eventual goal is for the transmitter to emulate enough of the ENTTEC DMX USB Pro serial protocol that common PC lighting software can send universe data directly to it.

## ENTTEC Compatibility

The eventual PC-facing interface should emulate the relevant portions of the ENTTEC DMX USB Pro protocol.

This should be developed as its own feature.

Do not mix ENTTEC parsing implementation into unrelated wireless or receiver tasks.

The initial requirement is primarily to accept full-universe DMX updates from existing lighting software.

## Receiver Telemetry

Receivers send low-rate telemetry back to the transmitter.

Telemetry is separate from the realtime DMX broadcast.

Expected telemetry includes:

* receiver ID
* uptime
* battery-low state
* last completed wireless sequence
* complete universes received
* incomplete/dropped universes
* malformed packets
* time since last valid universe
* RSSI/link information where QuickESPNow exposes it
* firmware version
* protocol version

Telemetry should occur approximately every 3-5 seconds with timing offsets/jitter so all receivers do not transmit simultaneously.

Feature 10 receiver implementation uses a compact packed telemetry packet sent
as an ESP-NOW broadcast. Each receiver derives a deterministic initial phase
from its ESP8266 chip ID, adds per-cycle jitter, and uses bounded retry backoff
when the QuickESPNow transmit queue is busy. This is decentralized collision
avoidance; it reduces synchronized transmissions but does not claim guaranteed
delivery. Telemetry is sent only from the receiver main loop and never blocks
the wireless receive callback.

Telemetry must remain lower priority than realtime DMX reception.

The production transmitter sketch at `./Firmware/Transmitter/transmitter.ino` accepts
ENTTEC DMX USB Pro input and processes received telemetry internally. UART0 is
the binary ENTTEC input, so text output is disabled by default and must not be
enabled during normal operation. The transmitter retains only the newest
completed serial universe and broadcasts snapshots at the configured wireless
refresh rate.

For bench diagnostics only, `TRANSMITTER_TELEMETRY_LOGGING` and
`TRANSMITTER_VERBOSE_LOGGING` can enable text output, but doing so makes UART0
unsuitable for simultaneous ENTTEC input and must not be used for protocol or
refresh-rate measurements. With telemetry logging disabled, packets are still
received, validated, and drained:

```bash
./flash_transmitter.sh --define=-DTRANSMITTER_TELEMETRY_LOGGING=0
```

`completeUniverses` is a 32-bit counter inside the 47-byte telemetry packet,
sent once per approximately 4–5 second telemetry report (not per DMX fragment).
At 1 Hz, a 7-hour run is 25,200 universes; even at 40 Hz it is 1,008,000,
well below 4,294,967,295. The receiver saturates this counter instead of
wrapping it. Its 4-byte contribution is negligible relative to the three
DMX fragments and does not materially affect airtime.

## Receiver Identification

Receivers should derive a persistent identifier from the ESP8266 MAC address, chip ID, or another built-in unique value.

A short human-readable representation should also be available, for example:

```
RX-A31F
```

A pairing/configuration system is not currently required.

## Future Management Interface

A future transmitter feature may expose a small status panel showing information such as:

```
Receiver    Battery    Link    Dropped    Last Seen

RX-A31F       OK       Good       0         1.2s
RX-728B       LOW      Good       2         0.8s
RX-19C2       OK       Fair      14         1.7s
```

This is NOT part of the initial implementation.

The telemetry architecture should merely avoid making such an interface difficult to add later.

Feature 11 adds a binary host-management protocol to the transmitter. The
transmitter accepts a CRC-16 protected `GET_RECEIVER_TELEMETRY` request framed
with `A5 5A`, and returns multipart telemetry records using the same framing.
Each part contains up to four fixed-size records, so the receiver cache can be
larger than 16 devices without requiring one large response buffer. The
protocol is intended for a host bridge/daemon: that program can expose a
virtual ENTTEC-compatible serial port to lighting software while providing a
separate management API for telemetry. The ESP8266 continues to receive normal
ENTTEC frames and does not emit diagnostic text by default.

## Fail-Safe Philosophy

The realtime system favors fresh state over guaranteed delivery.

Do not retransmit obsolete DMX universes merely to guarantee delivery.

Expected behavior:

```
lost wireless fragment
    -> discard incomplete universe

lost wireless universe
    -> retain previous active universe

transmitter temporarily disappears
    -> continue outputting previous universe

newer universe arrives
    -> accept it when complete

PC produces updates faster than RF link
    -> discard obsolete unsent states
```

This is appropriate because an old lighting command generally has less value than the newest available state.

## Coding Guidelines

Prefer:

* fixed-size buffers
* static allocation
* non-blocking state machines
* `millis()` / `micros()` scheduling
* short wireless callbacks
* named constants
* explicit packet structures
* compile-time assertions
* small modules with clear responsibilities
* comments around hardware-specific behavior

Avoid:

* unnecessary dynamic allocation
* `String` in timing-sensitive code
* long blocking delays
* unbounded queues
* unnecessary abstraction
* FreeRTOS
* PlatformIO
* guessed library APIs

Inspect the locally checked-out QuickESPNow and espDMX source whenever their behavior is uncertain.

## Dependency Revisions

**QuickESPNow** and **espDMX** are third-party dependencies maintained in the
project's GitHub forks and pinned in `./Libraries/`. **DMXUART** is a bundled
third-party source copy used by the physical-DMX retransmitter.

The wireless protocol definition (`WirelessDMX`) is a **project-owned local
library** (`./Libraries/WirelessDMX/`) — see Feature 5. It is not a git
dependency.

```
QuickESPNow
Current repository: https://github.com/aidancrowther/QuickESPNow
Upstream repository: https://github.com/gmag11/QuickESPNow
Commit: 27f88ad99e4b58958934c3a3dfabd62ccd338c62
Local modifications: Preserved in the DMX Now fork

espDMX
Current repository: https://github.com/aidancrowther/espDMX
Upstream repository: https://github.com/mtongnz/espDMX
Commit: 608ce009edfeebc3bca44b184a9dc667de055284
Local modifications: Preserved in the DMX Now fork

DMXUART
Repository: https://github.com/casesolved-co-uk/DMXUART
Version: 4.0.3
Local copy: `./Libraries/DMXUART/`
```

These local copies MUST be used for compilation (see Build Information). A different
`QuickESPNow` version (2.4.0) exists in the user Arduino library directory
(`~/Arduino/libraries`); it must not be picked up by the compiler.

### Library API / Compatibility Observations (Feature 1)

QuickESPNow (ESP8266):

* Correct include: `#include <QuickEspNow.h>`.
* Precompiled global instance: `quickEspNow` (no local instance needed).
* Initialization: `quickEspNow.begin(channel, interface, synchronousSend)`.
  `channel` 0-14 selects the channel, `255` follows the current WiFi channel.
  `interface` is `WIFI_IF_STA` (default) or `WIFI_IF_AP`.
* Broadcast: `quickEspNow.sendBcast(payload, len)`;
  unicast: `quickEspNow.send(dstAddress, payload, len)`.
* Receive callback: `onDataRcvd(callback)` with signature
  `void(uint8_t* address, uint8_t* data, uint8_t len, signed int rssi, bool broadcast)`.
* Send-status callback: `onDataSent(callback)` with signature
  `void(uint8_t* address, uint8_t status)`.
* RSSI is available through the receive callback. The library subtracts ~100 dB
  from the raw `wifi_pkt_rx_ctrl_t.rssi` value; the library source comments note
  the result "should be in dBm" but the offset is not fully understood.
  Treat RSSI values as relative until hardware testing.
* Max payload: `ESPNOW_MAX_MESSAGE_LENGTH` = 255 bytes;
  `ESP_NOW_MAX_DATA_LEN` = 250 bytes is the actual transmit limit enforced by
  `send()`. A 512-channel universe will require fragmentation.
* The ESP8266 implementation uses the classic `espnow.h` API,
  `ESP8266WiFi.h`, and `ETSTimer` tasks. It compiles cleanly against
  `esp8266:esp8266` core 3.1.2.
* `DEBUG_LEVEL` is undefined in the local copy, so the debug-logging path
  (and its optional `QuickDebug.h` dependency) is compiled out. No patch needed.

espDMX:

* Correct include: `#include <espDMX.h>` (library name is "espDMX").
* Pre-declared global instances: `dmxA` (UART0/GPIO1), `dmxB` (UART1/GPIO2).
  Instantiate locally to avoid conflicts; we use `dmxA` on UART0.
* `begin()` initializes the library (no parameters needed for default no-LED mode).
* Output is interrupt-driven (UART TX-FIFO-empty ISR); no `update()` call required.
* `setChans(data, numChans, startChan)` (1-based) sets channel data.
* BREAK (~115 µs) / MAB (~7 µs) via GPIO bit-bang, then 250000 baud 8N2.
* Self-refreshes at 44 Hz+; full 512-channel frame at least once per second.
* Trailing-zero channel trimming (min 30, +30 headroom).
* Compiles unmodified against esp8266 core 3.1.2 (verified).
* Hardware-verified 2026-08-21: full 512-channel universes, channels ≥255, BREAK/MAB accepted by fixture; continuous self-refresh on UART0/GPIO1 without library patches.

## Build Information

Receiver target:

```
esp8266:esp8266:generic
```

Libraries are pinned to the local project copies via `--library`, so the
compiler must not resolve them from `~/Arduino/libraries` (which contains a
newer, incompatible `QuickESPNow` 2.4.0).

Shared protocol header:

The wireless protocol is defined once in the project-owned library
`./Libraries/WirelessDMX/`. The flash scripts pin it alongside QuickESPNow via
`--library`, so the sketches include it by name:

```
#include <wireless_protocol.h>
```

### Receiver

Verified 2026-08-21 against `esp8266:esp8266` core 3.1.2, arduino-cli 1.4.1.
Re-verified after library replacement (ESP-Dmx → espDMX):

```
arduino-cli compile \
  --fqbn esp8266:esp8266:generic \
  --library ./Libraries/QuickESPNow \
  --library ./Libraries/espDMX \
  ./Firmware/Receiver
```

Result: success (exit 0). Flash usage 241,696 / 1,048,576 bytes (23%),
RAM 28,932 / 80,192 bytes (36%). Verbose output confirmed both libraries were
compiled from `./Libraries/QuickESPNow` (v0.8.1) and `./Libraries/espDMX`
(commit 02eb697f...); only the core-provided `ESP8266WiFi` library was taken from the
installed board package.

#### Flashing (receiver)

The ESP-01 is socketed and programmed via esptool after removal from hardware:

```bash
./flash_receiver.sh
```

This script compiles and flashes to `/dev/ttyUSB0`. Adjust the port as needed.

### Transmitter

The Feature 5 wireless transmitter test remains at `./Tests/espnow_universe_tx/`.
The production `./Firmware/Transmitter/transmitter.ino` sketch now accepts ENTTEC DMX
USB Pro input while retaining the verified wireless fragmentation and telemetry
processing paths.

Verified 2026-08-24 against `esp8266:esp8266` core 3.1.2, arduino-cli 1.4.1,
via `./flash_espnow_tx.sh` (compile-only, no `-f`):

```
arduino-cli compile \
  -b esp8266:esp8266:generic \
  --library ./Libraries/QuickESPNow \
  --library ./Libraries/WirelessDMX \
  ./Tests/espnow_universe_tx
```

The receiver test (`./Tests/espnow_universe_rx/`) builds the same way via
`./flash_espnow_rx.sh`. Both pin the shared protocol header
`./Libraries/WirelessDMX/` via `--library` and include it as
`#include <wireless_protocol.h>`. Flash with the `-f` flag when a serial
port is attached.

## Development Status

Update this section as features are completed.

### Feature 1: Project Setup / Dependency Verification

Status: COMPLETE (compile-verified 2026-08-21, not hardware-verified)

Completed:

* repository structure established (`./Firmware/Receiver/`, `./Libraries/`, `./shared/`, `./Firmware/Transmitter/`)
* QuickESPNow is pinned to the DMX Now fork
  `https://github.com/aidancrowther/QuickESPNow` at commit
  `27f88ad99e4b58958934c3a3dfabd62ccd338c62`; upstream is
  `https://github.com/gmag11/QuickESPNow`.
* espDMX is pinned to the DMX Now fork
  `https://github.com/aidancrowther/espDMX` at commit
  `608ce009edfeebc3bca44b184a9dc667de055284`; upstream is
  `https://github.com/mtongnz/espDMX`.
* both library APIs inspected (see Dependency Revisions)
* minimal receiver sketch created at `./Firmware/Receiver/receiver.ino`
  (defines pin constants, includes both libraries)
* both mandatory libraries verified to coexist in a single build
* successful compile against `esp8266:esp8266:generic` using the local library
  copies pinned via `--library` (see Build Information)
* exact build command documented (see Build Information)

Not done (intentionally out of scope for Feature 1):

* no ESP-NOW transmission or reception implemented
* no pin configuration or callbacks wired up
* no wireless packet structures, fragmentation, or buffering
* no ENTTEC serial input/parser

### Library replacement: ESP-Dmx → espDMX (basic usage)

Status: COMPLETE (compile-verified + espDMX hardware-verified 2026-08-21 ✓)

Completed:

* espDMX library integrated into `./Firmware/Receiver/receiver.ino` with minimal usage pattern:
  - `dmxA.begin()` initializes the library on UART0/GPIO1.
  - `dmxA.setChans(universe, DMX_UNIVERSE_CHANNELS, 1)` sets channel data;
    output is interrupt-driven and self-refreshing (no `update()` call).
* Channel-cycling test pattern preserved (one channel marked with 0xAA every 0.5s across all 512 channels).
* GPIO pin allocation unchanged (GPIO1 DMX data, GPIO2 DE control, GPIO3 battery low input).
* No patches applied to espDMX — the library compiles and works unmodified against core 3.1.2 on hardware.

Not done (intentionally out of scope for the original basic espDMX integration):

* no QuickESPNow wireless communication implemented
* no wireless packet structures, fragmentation, or buffering
* no ENTTEC serial input/parser
* no status/management interface

### espDMX hardware verification

Status: COMPLETE (hardware-verified 2026-08-21)

Verified items:

* full 512-channel universes transmitted continuously
* channels ≥255 included in moving test pattern (channel cycling across all 512 slots)
* channel 512 held at 0x01 to force full-universe transmission
* valid BREAK (~115 µs) / MAB (~7 µs) with 250 k baud 8N2 accepted by DMX fixture
* continuous self-refreshing output without explicit `update()` calls (interrupt-driven, ~44 Hz+)

Library state: espDMX works unmodified (commit 02eb697f...). No patches required.

Note: `Libraries/ESP-Dmx/` (Rickgg fork) and `Libraries/patches/*.patch` belong to the earlier abandoned approach; they are not used by this receiver build.

### Feature 5: Wireless DMX universe (fragmented broadcast)

Status: COMPLETE (hardware-verified 2026-08-24 ✓)

This is the first real wireless DMX data path: the transmitter broadcasts a
512-channel universe as 3 QuickESPNow fragments and the receiver validates each
fragment. Test sketches live under `./Tests/`:

* `Tests/espnow_universe_tx/` — Feature 5 transmitter (broadcast)
* `Tests/espnow_universe_rx/` — Feature 5 receiver (per-fragment validation)
* `Tests/espnow_basic_tx/` / `Tests/espnow_basic_rx/` — Feature 4 (basic link) sanity tests

Wire protocol (canonical, single source of truth):

* Defined once in the project-owned library `./Libraries/WirelessDMX/`
  (`src/wireless_protocol.h`). Both TX and RX include it; no per-program copies.
* `DmxFragmentPacket` is `__attribute__((packed))` and exactly 14 bytes
  (guarded by `static_assert(sizeof == DMX_HEADER_SIZE)`). A 14-byte header is
  followed by up to 236 bytes of channel payload (250-byte ESP-NOW max).
* 512-channel universe → 3 fragments: `offset 0/236/472`, lengths 236/236/40.

Root cause of the original "TX broadcasts but RX rejects" failure:

* `DmxFragmentPacket` was not packed, so the 4-byte-aligned `frameSequence`
  field inserted 3 padding bytes and shifted `payloadLength` from byte 13 to
  byte 16. The transmitter then wrote the DMX payload at byte 14
  (`+DMX_HEADER_SIZE`), clobbering `dataOffset`/`payloadLength`. The receiver
  read the corrupted `payloadLength = 2`, computed `14 + 2 = 16`, and rejected
  every packet (`RX FRAG size mismatch len=250 declared=16`). The two sides had
  also drifted into separate header copies, which masked the mismatch at compile
  time. Packing the struct (and consolidating to one header) resolved it.

Completed:

* transmitter sends all 3 fragments per universe and increments the frame
  sequence each frame; each fragment is broadcast at its true size and the
  QuickESPNow TX queue is drained (via `onDataSent`) before the next frame.
* receiver validates size/magic/version/type/payload-length/fragment bounds and
  verifies the first and last payload byte of each fragment against the
  deterministic test pattern `g_universe[i] = (i + seq) & 0xFF`.
* both sketches compile against `esp8266:esp8266:generic` and the failure above
  is resolved — receiver now accepts the transmitted fragments (hardware-verified).

### Feature 6: Receiver Reconstruction + Double Buffering

Status: COMPLETE (test verified 2026-08-27 ✓)

This feature adds receiver-side reconstruction of the complete 512-byte universe
from QuickESPNow broadcast fragments, with safe double buffering via two distinct buffers.

Test results are documented in `Testing/FEATURE6_RESULTS.md`. All 11/12 test cases
passed as demonstrated by the logs (Test 8 skipped due to missing hook build; source
code verified). The receiver implementation passes all test scenarios from the
[Feature 6 Test Plan](./Tests/FEATURE6_TEST_PLAN.md).

#### Architecture (no FreeRTOS)
- Plain Arduino `setup()` / `loop()` with a small deterministic state machine.
- The QuickESPNow receive callback runs in a ROM timer context and is kept MINIMAL: it only copies the received packet into a bounded static handoff ring (SPSC).
- `loop()` drains the ring, validates fragments, updates staging, runs the full 512-byte integrity check, and promotes by swapping pointers (no 512-byte copy).
- Only the ring head/tail are shared between callback and loop; they are guarded by the ESP8266 core's own context-safe critical section (`xt_rsil(15)` / `xt_wsr_ps`).

#### Buffers and Promotion
- Two 512-byte buffers: `stagingUniverse` (frame being assembled, may be incomplete) and `activeUniverse` (most recent complete, integrity-validated frame).
- Promotion occurs by pointer swap; after the swap the buffer that was active becomes the reusable staging buffer.
- Initial state: both buffers zeroed; `hasActiveWirelessFrame = false`.

#### Fragment Tracking
- A 512-bit coverage bitmap tracks which bytes of the staging universe have been covered by received fragments.
- A 32-bit unique-count + receive mask ensures duplicate fragments are not double-counted.
- Metadata consistency is verified against the current staging sequence (same fragment count, same universe ID).

#### Sequence Handling (wrap-safe)
- `seqIsNewer(a,b)` uses `(int32_t)(a - b) > 0` to treat rollover (`0xFFFFFFFF -> 0`) as forward progression.
- A newer fragment supersedes an incomplete staging frame; an older fragment is marked STALE.

#### Timeouts
- `STAGING_TIMEOUT_MS = 2000`: abandon a partially assembled frame after this much silence.
- `TRANSMITTER_RESET_RECOVERY_MS = 3000`: permit re-baselining to an older sequence only after the link has been quiet for this long (transmitter restarted).

#### Validation and Production Promotion
- Every build validates fragment wire format, protocol metadata, canonical tile
  offsets/lengths, non-overlap, expected-fragment count, and full 512-byte
  coverage before promotion.
- Production receiver builds then promote arbitrary DMX slot values; this is
  necessary because lighting data has no deterministic byte pattern.
- The former Feature 5 deterministic content check is retained only as an
  opt-in test build (`-DRX_VALIDATE_TEST_PATTERN=1`). In that mode,
  `universe[i] == (i + seq) & 0xFF` is additionally required and a
  corrupt-but-complete frame increments the integrity-failure counter without
  replacing the active universe.

#### Diagnostic Counters (local only, no telemetry)
- Packets received, valid fragments accepted, malformed fragments, duplicate fragments, stale fragments, incomplete frames abandoned, complete universes accepted, integrity failures, ring overflows, re-baselined events, last RSSI.

#### Compile Verification
Both sketches compile successfully via the existing scripts (compile-only, no flash):
  ```bash
  ./flash_espnow_tx.sh   # compile only
  ./flash_espnow_rx.sh   # compile only
  ```
Use `./flash_espnow_tx.sh -f` and `./flash_espnow_rx.sh -f` to compile and flash.

#### Test Hooks (Feature 6 fault injection, all DEFAULT OFF)
Test hooks are compile-time defines passed to the flash scripts with `--define` (added
to `build.extra_flags`); hook code is compiled out when the define is absent:
  ```bash
  ./flash_espnow_tx.sh --define -DTEST_DROP_FRAGMENT_INDEX=1
  ./flash_espnow_tx.sh --define -DTEST_DUPLICATE_FRAGMENT_INDEX=1
  ./flash_espnow_tx.sh --define -DTEST_REORDER_FRAGMENTS
  ./flash_espnow_tx.sh --define -DTEST_CORRUPT_FRAGMENT_INDEX=1
  ./flash_espnow_tx.sh --define -DTEST_DELAYED_FRAGMENT
  ./flash_espnow_tx.sh --define -DTEST_SEQUENCE_WRAP
  ./flash_espnow_rx.sh --define -DTEST_INJECT_MALFORMED
  ```
  - `TEST_DELAYED_FRAGMENT` (TX, Test 6): after each frame, holds ~2.5 s then re-sends one
    fragment of the already-active frame, so the receiver must classify it STALE.
  - `TEST_INJECT_MALFORMED` (RX, Test 8): at startup feeds one structurally-malformed
    packet through the receiver's own validation path (no RF required).

#### Feature 6 Testing Plan
A comprehensive testing plan exists at `Tests/FEATURE6_TEST_PLAN.md`. It documents 12 tests — normal frame reception, dropped fragments (middle/final), duplicate, reorder, late/stale fragment, corrupted payload, malformed metadata, mid-stream startup, transmitter reset re-baseline, uint32 sequence rollover, and multiple receivers. Each test lists the exact `--define` build setting(s) and the expected RX serial output/counter deltas (see the Test Hooks section above for the hook list).

#### RAM/Flash Usage (Receiver)
- RAM: 32,224 / 80,192 bytes (40%)
- Flash: 245,008 / 1,048,576 bytes (23%)

### Feature 7: Configurable Transmitter Refresh + Reliable-Rate Test Harness

Status: COMPLETE (hardware-validated 2026-09-02 ✓)

Makes the transmitter's wireless refresh rate configurable and adds a measurement
harness to find roughly what refresh rate the system sustains reliably.

Completed:

* **Budget pacing (Feature 7)**: the transmitter's per-frame overhead is now
  subtracted from the requested interval so period ≈ 1000/Hz. Implemented with
  `-DWIRELESS_TX_OVERHEAD_MS=27` and `-DWIRELESS_TX_DRAIN_TIMEOUT_MS=100` in
  `Tests/espnow_universe_tx.ino`. This fix addresses the ~27 ms constant added in
  series (radio airtime for a 512-channel frame) and tightens the drain timeout
  from 200 ms to 100 ms. Compile-verified at all rates.
* MEGA DMX monitor `Tests/dmx_refresh_monitor/dmx_refresh_monitor.ino`: sits on the
  integrated receiver's DMX output (DMXSerial RX on USART1/pin 19 via
  `-DDMX_USE_PORT1`), counts genuinely-new universes (on `packetReady()`, a one-shot
  latch per **complete** frame, filtered to new sequences so espDMX's ~44 Hz identical
  retransmits do not count), infers loss from frame-sequence gaps
  (channel 1 = `seq & 0xFF`), validates the full 512-channel pattern, and emits a
  metric line every second on the USB Serial (115200). Compile-verified
  (arduino:avr:mega, 6720 B program / 1031 B RAM); `-DDMX_USE_PORT1` confirmed on
  the `DMXSerial.cpp` library compile line (verbose build).
* `./flash_dmx_monitor.sh` — build/flash for the MEGA (passes the global
  `DMX_USE_PORT1` flag; `arduino-cli upload` for AVR).
* `Tests/pico_dmx_refresh_monitor/pico_dmx_refresh_monitor.ino` — optional
  Raspberry Pi Pico PIO/DMA monitor on GPIO 1 with native USB telemetry.
* `flash_pico_dmx_monitor.sh` — build/flash helper for the Pico monitor.
* `Testing/feature7/tools/run_sweep.py` — host runner that flashes the TX for
  each requested rate, captures monitor results, and writes a manifest.
* `Testing/feature7/tools/analyze.py` — parses result lines and applies the
  reliability criteria.
* `Testing/feature7/plan/FEATURE7_TEST_PLAN.md` — method, sweep rates, metric
  definitions, pass/fail bar, grounding requirement, and reproduction commands.
* `Testing/feature7/results/FEATURE7_RESULTS_20260902.md` — grounded hardware
  results, MEGA comparison, analysis, and recommendations.

Hardware validation:

* The final Pico PIO/DMA monitor was flashed and validated with the DMX source
  and Pico sharing ground.
* The 10 Hz smoke test recorded 99 updates at 9.90 Hz with 0 inferred loss and
  0 pattern errors.
* The full 5/10/15/20/22/25/27/30/32/35/37/40 Hz sweep completed successfully.
* Using the strict criteria of ≤5% inferred loss, zero pattern errors, and no
  sustained outage, the grounded Pico run supports a conservative reliable
  ceiling of **20 Hz**. The 22 Hz point is a transition case requiring repeat
  testing; 30–40 Hz reaches approximately 31–32 Hz throughput but fails full
  universe validation because of pattern errors.
* The MEGA comparison run passed through 22 Hz. The monitor boundary difference
  is documented rather than treated as proof of a board-specific system limit.
* The fresh post-logging-cleanup MEGA sweep (`Testing/feature7/runs/20260902_174631/`)
  was completed on TX `/dev/ttyUSB0` with the analyzer on `/dev/ttyUSB1`; the
  analyzer was reflashed first and all 12/12 rate captures succeeded. The
  results reproduce a conservative reliable ceiling of 20 Hz.

### Feature 8: ENTTEC DMX USB Pro Serial Input/Parser

Status: SUBSTANTIALLY COMPLETE (implemented and hardware-verified 2026-09-03)

The integrated transmitter at `./Firmware/Transmitter/transmitter.ino` accepts the
ENTTEC DMX USB Pro packet format on UART0:

```text
0x7E | label | length LSB | length MSB | payload | 0xE7
```

`SEND_DMX_PACKET` (`0x06`) is supported. Its payload must contain DMX start
code `0x00` followed by 1–512 channel slots. Valid packets are committed only
after the complete payload and terminator are received. Short universes clear
unused channel slots, preventing stale values from remaining active.

Parsing is performed by a bounded, non-blocking byte state machine. It accepts
partial serial reads, rejects malformed/oversized/unsupported packets without
changing the current universe, and retains only the newest completed serial
universe. Each wireless transmission takes a fixed snapshot before its three
fragments are queued, preventing a frame from mixing two input universes.

UART0 is configured for `115200 8N2`, the DMX USB Pro serial format. Telemetry
packets continue to be received and validated, but telemetry and diagnostic
text output is disabled by default because UART0 is the binary ENTTEC input.

The 115200-baud input supports the validated 20 Hz full-universe operating rate
with the available serial headroom. Higher wireless rates can be selected
explicitly for experimentation, but 40 Hz full-universe serial input requires a
higher baud rate than 115200.

#### Feature 8 verification summary

Hardware verification used an ENTTEC-compatible serial source, an ESP8266
transmitter, the production receiver firmware, the receiver MAX3485 DMX output,
and an Arduino Mega monitor on USART1. The canonical evidence is indexed in
`./Testing/feature8/plan/FEATURE8_HARDWARE_TEST_PLAN.md` and retained under
`./Testing/feature8/runs/canonical/`.

Verified on 2026-09-03:

* four-case end-to-end smoke suite: 4/4;
* parser and boundary suite: 13/13;
* serial delivery/load suite: 3/3 after correcting the test oracle to account
  for the latest-state wireless design;
* fragment reorder, duplicate, dropped-fragment, delayed-fragment, and sequence
  rollover tests: all defined cases passed;
* production 30-minute soak: 1,800 seconds, 79,882/79,882 DMX frames matched,
  zero content failures, and 59/59 monitor liveness polls passed.

This is substantial hardware completion of Feature 8. Remaining work is
limited to optional/manual coverage outside the automated TX-to-Mega pipeline:
physical DMX waveform inspection, deliberate receiver power/RF interruption
and recovery, simultaneous comparison of both receivers, cold/warm repeat
runs, and any additional long-duration environmental testing. The current
production protocol intentionally has no payload checksum; the fault test
documents that limitation rather than claiming payload-corruption detection.

### Feature 9: Low-Battery GPIO Monitoring

Status: COMPLETE (hardware-verified 2026-09-02 ✓)

Completed:

* Receiver monitors the external active-HIGH low-battery comparator on GPIO3 / UART RX.
* The input is debounced in the receiver main loop using configurable
  `BATTERY_LOW_ASSERT_MS` (default 2000 ms) and `BATTERY_LOW_CLEAR_MS` (default
  5000 ms) hysteresis periods.
* The internal `batteryLow` flag is included in receiver telemetry.
* For hardware verification, the receiver outputs `0xFF` on all 512 DMX
  channels while the debounced flag is asserted, then restores the latest
  complete wireless universe after the flag clears.
* No receiver Serial diagnostics are used because UART0 is dedicated to DMX output.

### Feature 10: Receiver Telemetry

Status: COMPLETE (hardware-verified with multiple receivers 2026-09-02 ✓)

Completed:

* Receivers broadcast compact packed telemetry approximately every 4–5 seconds,
  with deterministic startup phase, jitter, and bounded retry backoff.
* The transmitter receives and validates telemetry from multiple receivers and
  reports receiver ID, MAC, uptime, battery state, sequence/counter data, RSSI,
  firmware, and protocol information.
* Telemetry is handled through a bounded callback-to-loop ring and does not
  perform Serial I/O in the wireless callback.
* `TRANSMITTER_TELEMETRY_LOGGING` independently controls telemetry display and
  defaults to disabled. Set it to `1` only for bench diagnostics; keep it at
  `0` during ENTTEC operation because text output would corrupt the binary UART
  stream. Telemetry processing remains active while display is suppressed.
* The `completeUniverses` counter is a saturating 32-bit value. Its four-byte
  field is sent only once per telemetry report and is safe for the expected
  5–7 hour runtime.

Hardware verification confirmed telemetry operation with multiple receivers.
The implementation is intentionally complete before the future status/management
interface and ENTTEC input features.

The Feature 11 extended acceptance run operated the integrated transmitter at
20 Hz for 660 seconds while the Arduino Mega monitor verified the receiver DMX
output. All 13,200 submitted input frames were sent at 20 Hz, the Mega recorded
29,290 correct frames with zero failures, and 43/43 telemetry reports covering
two receivers passed CRC and multipart validation. Mean telemetry latency was
55.23 ms and maximum latency was 55.58 ms. Detailed evidence is retained under
`./Testing/feature11/runs/20hz-extended/`.

Follow-up (not required for Feature 7 completion):

* Repeat the 20/22/25 Hz boundary points across multiple runs if a production
  ceiling above 20 Hz is required.

### Future Features

Expected approximate sequence:

1. Project setup and dependency verification ✓
2. Patch espDMX library to match hardware requirements (if needed) — *resolved (not required)*
3. Hardware verification of espDMX output (channels ≥255, full 512-channel transmission) — *verified 2026-08-21*
4. Basic QuickESPNow Firmware/Transmitter/receiver communication ✓
5. Wireless packet format and fragmentation ✓ (Feature 5, verified 2026-08-24)
6. Receiver universe reconstruction/double buffering ✓ (Feature 6, verified 2026-08-27)
7. Configurable transmitter wireless refresh + reliable-rate test harness ✓ (hardware-validated 2026-09-02; conservative reliable ceiling 20 Hz)
8. ENTTEC serial input/parser ✓ (substantially complete; hardware-verified
   2026-09-03; optional manual physical/repeat coverage remains)
9. Low-battery GPIO monitoring ✓ (hardware-verified 2026-09-02)
10. Receiver telemetry ✓ (multi-receiver hardware-verified 2026-09-02)
11. Status/management interface ✓ (substantially complete for current Linux/20 Hz deployment)
12. Reliability and throughput testing ✓ (Feature 12 complete for validated Linux/20 Hz deployment)
13. Hardware-specific cleanup and fail-safe refinement
14. High-priority transmission ✓ (targeted receiver ACK and retry path hardware-validated)
15. Channel gating ✓ (daemon filtering, receiver runtime hard-gate fail-safe, and Mega validation)
16. Management-only daemon/transmitter role and standalone physical-DMX re-transmitter ✓

This ordering may change as hardware testing reveals constraints.

### Feature 16: Management-only coexistence and physical-DMX re-transmitter

Status: COMPLETE (hardware-validated 2026-09-17 ✓)

The daemon now has a bridge-mode default plus an explicit `management_only`
role. Management-only mode does not start ordinary DMX inputs or emit normal
DMX, while telemetry, receiver controls, and explicit priority/gate traffic
remain available. The integrated transmitter has a compile-time
`TRANSMITTER_MANAGEMENT_ONLY` role with the same normal-DMX suppression.

A standalone `Firmware/ReTransmitter/` sketch receives physical DMX on UART0/GPIO3
using the pinned MIT-licensed `DMXUART` receive implementation and sends
only the existing normal three-fragment protocol. Its helper supports channel,
universe, refresh-rate, optional partial-universe zero-fill flags, and an
interactive `--menuconfig` prompt. Strict 512-slot input remains the default.

Host coverage currently passes 121 tests. Bridge transmitter, management-only
transmitter, re-transmitter, and receiver compile checks pass with ESP8266 core
3.1.2; measured IRAM usage is 91%, 91%, 92%, and 92%, respectively.

The standalone re-transmitter production target is 10 Hz, while the native and
integrated transmitter target remains 20 Hz. Production pacing uses an absolute
100 ms deadline with overrun rebasing, waits for a fresh complete physical-DMX
frame, and never reuses a stale universe. Strict boundary and transition cases
cover 24 through 512 slots, including long 512-, 24-, and 237-slot soaks.

The flashed production image completed the extended retransmitter validation
with matching reconstructed content for every accepted promotion, no source
mismatches, no corruption, no sequence backtracks, and no queue/ring failures.
Long-run measurements were approximately 8.9–9.9 Hz, within the documented
measurement tolerance for the nominal 10 Hz target. Deployment and recovery
procedures are documented in `Docs/retransmitter-deployment.md`.

The re-transmitter has no planned diagnostic or auxiliary I/O beyond UART0 DMX
RX and ESP-NOW; future hardware I/O can be added without changing the protocol.

### Feature 12: Reliability and throughput testing

Status: COMPLETE for the validated Linux/20 Hz ESP8266/Firmware/Transmitter/Firmware/Receiver/
Arduino Mega deployment.

The 30-minute two-receiver acceptance submitted 36,000 DMX frames at 20 Hz and
recorded 79,869/79,869 passing Mega checks. Thirty priority events produced 60
receiver completions with zero event failures, retries, invalid ACKs, or
unknown ACKs. The two-receiver hard-gate acceptance passed both lock and unlock
transactions, with gate-applied ACKs from both receivers on the first attempt
and zero Mega failures in all measurement windows.

Hardware-intervention coverage also passed:

* receiver removal and reconnection;
* transmitter reset while the daemon remained running;
* daemon stop/restart with receiver rediscovery and cache clearing;
* PTY client disconnect and reconnection.

Each recovery preserved valid normal DMX output. Fresh priority transactions
after recovery completed with both receiver ACKs on the first attempt and zero
retries. The final 20-event two-receiver soak also completed with 20/20
first-attempt successes and no failed, invalid, unknown, or retry-failed events.

The receiver priority staging timeout was aligned with the daemon's four-second
priority transaction budget so 1 Hz priority fragments and gate metadata remain
valid across the complete transaction window. The host suite passes 66 tests.

### Feature 15: Channel Gating

Status: COMPLETE for the validated two-receiver Linux/20 Hz deployment.

The daemon now supports three per-channel states: `OPEN`, `MANAGEMENT_ONLY`,
and `LOCKED`. Serial and Art-Net frames update only open channels; management
editing may update open, management-only, and locked channels. Locked channels
cannot be changed by ordinary source or retransmitter data. In management-only
mode, entering `LOCKED` captures the currently observed value before later
observations are blocked. Mixed frames preserve protected channel values while
applying permitted changes to the remaining channels.

Gate assignments are persisted in TOML under `[channel_gates]` using
`management_only` and `locked` channel lists. The universe editor uses `l` to
cycle the selected channel's gate; `g` retains its existing grid command.
Automated coverage includes source blocking, management permissions, locked
value preservation, management-only observed-value capture, configuration round
trips, validation, and dashboard help.

The receiver-side fail-safe is implemented with a runtime 512-byte normal-write
permission table and a no-gates fast path. Priority gate metadata is staged
separately from the priority DMX fragments and is applied only after complete
priority reconstruction. The transmitter waits for metadata queue/send
confirmation before sending priority fragments, and receiver completion ACKs
identify gate metadata application.

The two-receiver hard-gate path was hardware-validated on 2026-09-10:

* Priority gate establishment: 266/266 checks passed.
* Normal traffic remained blocked at the locked priority value: 266/266 passed.
* Priority unlock: 267/267 checks passed.
* Normal output resumed after unlock: 266/266 checks passed.
* Both receivers reported gate-applied completion on lock and unlock.
* A 20-event two-receiver priority soak completed with 20/20 first-attempt
  successes, zero failures, and zero invalid or unknown ACKs.

Runtime-only locks reset to open on receiver reboot by design. Native
Windows/macOS serial support and longer optional soak runs remain non-blocking
follow-up work.

### Feature 17: Management-only observed universe display

Status: IMPLEMENTED (compile- and host-test verified; hardware observation
validation pending)

Management-only transmitters passively receive ordinary three-fragment DMX
universes from the standalone physical-DMX retransmitter using the existing
QuickESPNow receive path. They reconstruct complete universes in a bounded
loop-side state machine and expose the latest snapshot through management opcode
`0x0A` / response opcode `0x8A` as three CRC-protected parts. This does not use
Wi-Fi promiscuous mode and does not make the management transmitter a competing
normal-DMX source.

The daemon polls the snapshot at approximately 4 Hz only in management-only
mode. Observed state is separate from the editable manual universe and never
enters the DMX pacer. Since a transmitter cannot receive its own ESP-NOW
broadcast, locally sent priority data supplies the initial display fallback.
Complete retransmitter observations supersede non-locked channels. Entering a
hard lock captures the current observed value; later retransmitter updates cannot
replace it, while explicit management edits remain allowed.

The dashboard labels the display `LIVE`, `STALE`, or `UNAVAILABLE` and shows its
source, age, and sequence. The feature is optional QoL telemetry: observation
loss must not affect normal receiver output, retransmission, telemetry, or
priority control. Host tests and ESP8266 compilation pass; live RF/UART
validation remains follow-up work.

### Feature 18: Retransmitter telemetry and remote controls

Status: COMPLETE (host/firmware implementation, hardware acceptance, and extended
validation completed)

The next management-plane extension adds a distinct retransmitter telemetry
identity and bounded cache rather than treating a retransmitter as a receiver.
Retransmitters broadcast best-effort telemetry on the same low-priority
schedule as receiver telemetry. The scheduler is deterministic and abandons a
report in favor of physical-DMX capture, normal wireless fragments, or
priority/control traffic; it never creates a queue or catch-up burst. Production
operation is approximately 10 Hz for the retransmitter's normal universe cadence.
Telemetry is
always abandoned in favor of physical-DMX capture, normal wireless fragments,
or priority/control traffic; it must never create a queue or a catch-up burst.

The battery field reports `UNKNOWN` for builds without the optional comparator and
reports the comparator state for production builds compiled with
`--battery-monitor`. Retransmitter telemetry reports the always-enabled input
state, physical-DMX freshness, learned slot count, wireless counters, locate
state, battery state, and the last applied control-generation compatibility
field. Receiver telemetry also exposes effective output state, locate state, and
whether any hard gate is active, so stale runtime test state is visible to
operators.

Retransmitter locate uses a dedicated repeated control packet through the
management transmitter's priority-control path. Locate is intentionally
disruptive: it pauses DMX input and wireless scheduling while GPIO2 pulses the
locate indicator, then resumes reception. The attempted GPIO2 DMX input-gating
experiment was reverted because it disabled the previously functional locate
output; production firmware does not remotely enable or disable retransmitter
DMX input.

The management dashboard shows retransmitters in a separate panel only after one
is discovered, with persistent aliases, independent freshness, and a carousel
for multiple devices. Receiver and retransmitter state remain separate, while
telemetry-based control generations provide confirmation without requiring a
separate ACK for every control packet. Priority ACKs remain available for
transaction diagnostics and the priority status panel stays visible long enough
to inspect ACK timing.

Production acceptance passed with valid reconstruction, zero post-sync CRC
errors, source mismatches, sequence backtracks, and send failures. Extended
validation passed 25/27 cases; the two reported failures were Mega source-result
capture/rate-reporting issues, while retransmission integrity passed. The
production retransmitter and diagnostic receiver were restored/validated as
required and the result was committed as `e716a05`.

After that historical validation, the production retransmitter was reflashed with
the restored GPIO2 locate design and locate operation was verified. A 30-second
post-reflash smoke test captured 356 valid diagnostic normal-DMX records, source
sequences 12 through 370, input frames `0 -> 253`, wireless frames `0 -> 252`,
and zero wireless send failures. The verified live mapping was `/dev/ttyUSB0`
management transmitter, `/dev/ttyUSB1` diagnostic receiver at 460800 baud, and
`/dev/ttyUSB2` Mega source.

### Feature 11: Host Status and Management Interface

Status: COMPLETE for the current Linux/20 Hz deployment.

Completed:

* Binary CRC-protected transmitter management protocol.
* Multipart receiver telemetry reports and bounded receiver cache.
* Telemetry freshness, timeout recovery, and scheduler status reporting.
* Linux host daemon with ENTTEC parser, 20 Hz latest-state pacer, reconnecting
  transmitter connection, and virtual serial PTY backend.
* Configurable Art-Net ArtDMX input, virtual serial input, and source policy.
* Optional raw-DMX Linux PTY accepting complete 512-byte universes, with source
  arbitration and a default one-second incomplete-burst timeout. The raw-DMX
  hardware run passed 133/133 Mega checks before and after a timed-out partial
  burst, with one timeout drop recorded.
* TOML configuration under `configs/`, read-only default/example baselines,
  interactive configuration selection, last-writable-config reopening, atomic
  Save As support, and dashboard setup editing.
* btop-like curses dashboard with color-coded telemetry visualizations and
  Advanced hardware-testing controls.
* 66 automated host tests and live Art-Net/Firmware/Transmitter/receiver
  validation.
* 30-minute end-to-end acceptance run with 36,000 DMX frames submitted at 20 Hz,
  79,869/79,869 Mega DMX checks passing, zero failures, and two receivers
  observed.

The receiver management controls also include targeted/broadcast MAX3485 output
control and a deliberately disruptive GPIO1/GPIO2 locator. The locator suspends
the UART-backed espDMX engine, releases GPIO1 to GPIO mode, and runs for a
15-second default interval (explicit requests may use 1–15 seconds). These
controls are compile-verified and require off-fixture hardware validation before
being treated as production-safe.

Remaining non-blocking follow-up work:

* Native Windows/macOS virtual serial backends.
* Broader QLC+ version/platform validation.
* Additional transmitter disconnect/reconnect fault-injection testing.
* Production packaging, service installation, and GUI frontend.

## Important Development Rule

Do not treat this README as evidence that a feature already exists.

It describes the intended architecture.

Check the actual source and Development Status before assuming functionality has been implemented.

Likewise:

```
successful compilation != successful hardware validation
```

Hardware-dependent behavior must be tested on real ESP8266/MAX3485/DMX hardware before being considered complete.

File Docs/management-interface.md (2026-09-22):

# Management interface

The DMX Now management interface is a binary, CRC-protected control plane that
shares the transmitter UART with the ENTTEC DMX stream. It is intentionally
separate from normal DMX payloads and never emits diagnostic text during normal
operation.

Management interface flow

## Frame format

Every host-to-transmitter management frame is:

```text
A5 5A | version | opcode | length low | length high | payload | CRC low | CRC high
```

The CRC is CRC-16/CCITT over `version`, `opcode`, `length`, and `payload`; the
two sync bytes are excluded. The transmitter parser is byte-wise, bounded, and
recovers by searching for the next sync sequence after malformed input.

## Host request opcodes

| Opcode | Name | Payload | Response/behavior |
|---:|---|---|---|
| `0x01` | Get receiver telemetry | empty | Multipart telemetry response. |
| `0x02` | Mark next priority | priority ID, target, repeats, attempt, optional gate mask | Transmitter classifies the next complete ENTTEC universe as priority. |
| `0x03` | Get priority ACKs | empty | Bounded priority ACK report. |
| `0x04` | Clear receiver cache | empty | Clears transmitter telemetry/ACK cache and returns cache-cleared response. |
| `0x05` | Set receiver fail-safe | mode, timeout, generation | Transmitter broadcasts the receiver configuration three times. |
| `0x06` | Set receiver output | enabled, target ID, generation | Transmitter broadcasts a targeted or all-online MAX3485 output change. |
| `0x07` | Locate receiver | target ID, duration, generation | Receiver disables DMX and pulses GPIO1/GPIO2 for the requested interval; the default is 15 seconds and the valid range is 1–15 seconds. |
| `0x08` | Set transmitter mode | one byte: `0` bridge or `1` management-only | Changes the runtime transmitter role unless the firmware was statically locked. Response `0x88` reports accepted/rejected status and active mode. |
| `0x09` | Get transmitter mode | empty | Queries the current runtime role without changing it. Response `0x88` reports the active mode. |
| `0x0A` | Get observed universe | empty | Returns three CRC-protected `0x8A` parts containing the latest complete normal-DMX observation or the transmitter's local fallback. |
| `0x0B` | Retransmitter locate | target ID, duration, generation | Priority-queued locate packet; locate state is confirmed by retransmitter telemetry. Production retransmitters keep DMX input enabled and use GPIO2 for the locate indicator. |

The Python codec is in:

```text
Host Software/wireless_dmx_daemon/wireless_dmx/transmitter/management.py
```

The shared embedded declarations are in:

```text
Libraries/WirelessDMX/src/wireless_protocol.h
```

## Queueing and ordering

The transmitter has separate bounded queues for:

- latest-state normal DMX;
- ordinary management requests;
- priority management markers.

The daemon queries the current mode after connection and reconnect. If it does
not match the configured role, it sends a mode-set request and waits for the
accepted response before clearing the receiver cache. Firmware may be statically locked with
`TRANSMITTER_LOCK_BRIDGE` or `TRANSMITTER_LOCK_MANAGEMENT_ONLY`; a rejected
request leaves the current firmware role unchanged. The legacy
`TRANSMITTER_MANAGEMENT_ONLY` define remains an alias for a locked
management-only image.

Priority markers are serviced ahead of ordinary management traffic so telemetry
polling cannot silently turn a priority universe into a normal universe. Normal
DMX remains latest-state: a newer unsent universe replaces an obsolete one.

## Telemetry flow

1. The daemon clears the transmitter receiver and retransmitter caches.
2. After the cache-cleared response, it periodically requests telemetry.
3. The transmitter collects receiver broadcasts in a bounded table.
4. A multipart telemetry report is serialized over the host UART.
5. The daemon groups parts by report sequence and validates part indexes before
   publishing receiver state.

Telemetry includes receiver identity, link age, battery state, RSSI, uptime,
universe counters, firmware/protocol versions, telemetry sequence, and fail-safe
configuration/state.

Friendly receiver names are host-side aliases and are not part of the embedded
telemetry protocol. The daemon persists them under `[receiver_names]`, keyed by
the receiver's hexadecimal 32-bit ID. This keeps naming independent of firmware
and preserves the hardware ID for targeted management commands.

## Priority and ACK flow

The daemon creates a unique priority ID and sends a marker. The transmitter
marks the next complete host universe, sends priority fragments at the priority
cadence, and receives completion packets from receivers. The transmitter stores
ACK records in a bounded ring and exports them when polled.

The daemon evaluates ACKs per event, receiver, and attempt. A hard-gate event is
complete only when every expected receiver reports
`PRIORITY_COMPLETE_GATE_APPLIED`; an ordinary priority ACK is not sufficient.

Repeated physical ACK records are tracked as duplicate records without turning a
successful logical event into a failure.
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

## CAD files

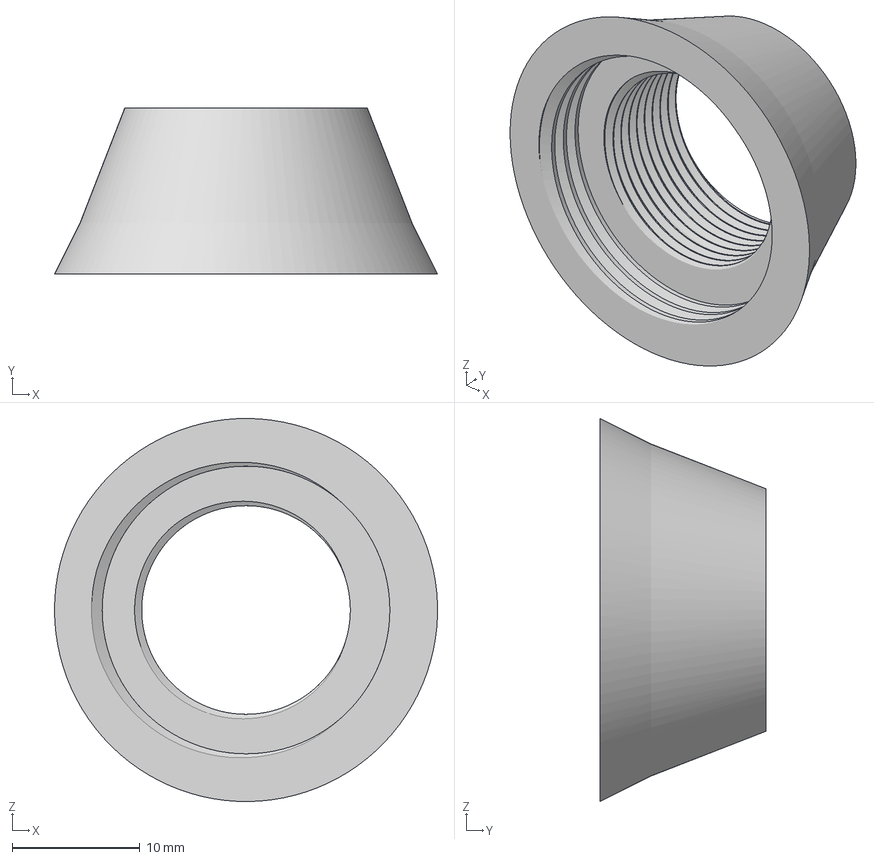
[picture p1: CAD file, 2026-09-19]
Hardware/3D Models/Receiver Enclosure/XLR Connector Thread.3mf
30.0 x 13.0 x 30.0 mm

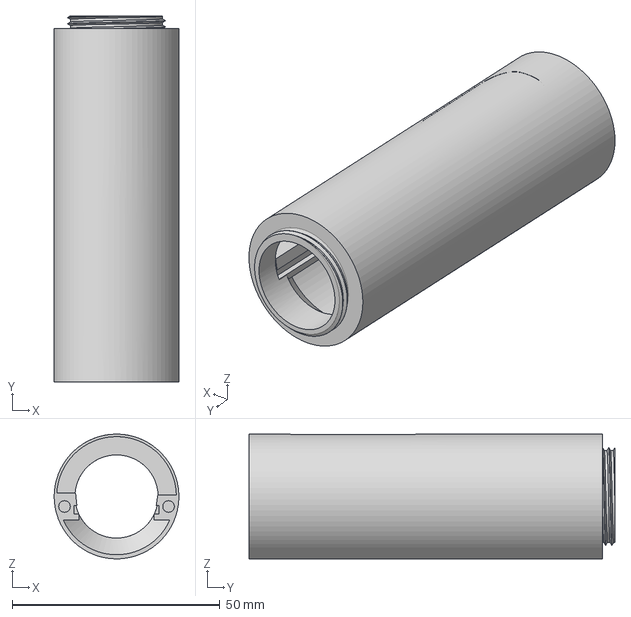
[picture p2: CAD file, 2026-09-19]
Hardware/3D Models/Receiver Enclosure/Device Body - Recessed Window.3mf
30.0 x 88.0 x 30.0 mm

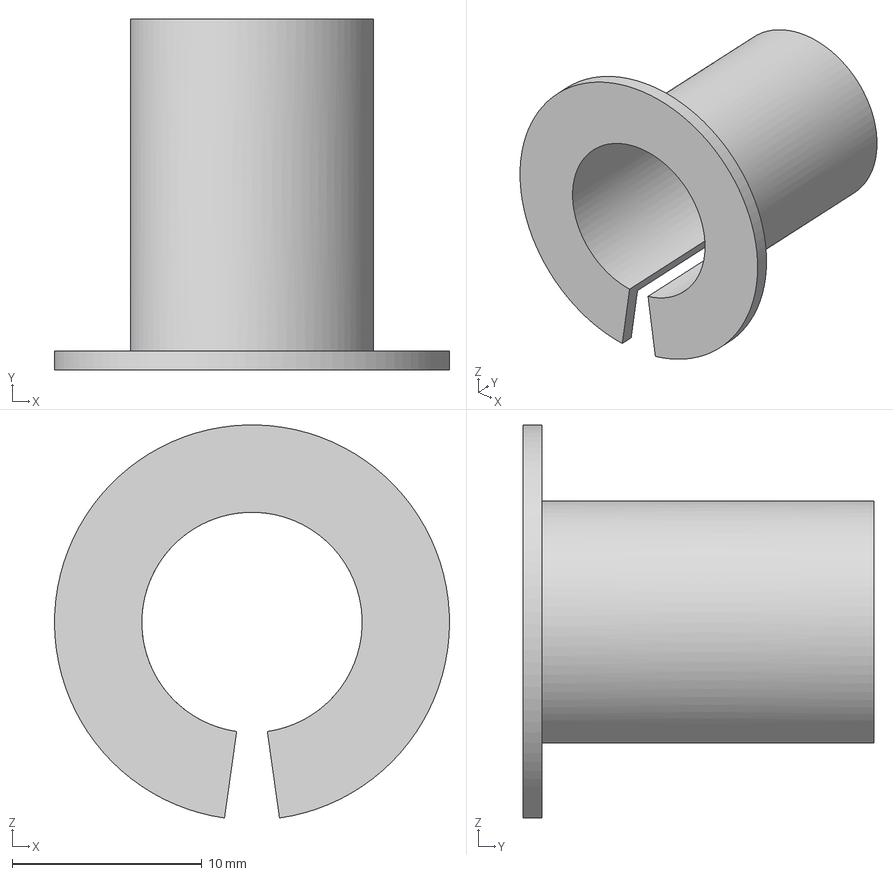
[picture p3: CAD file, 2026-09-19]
Hardware/3D Models/Receiver Enclosure/Insert Retainer.3mf
20.8 x 18.5 x 20.7 mm

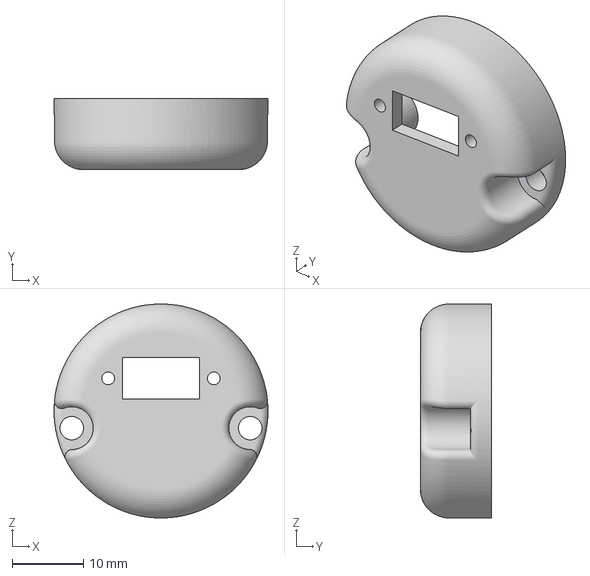
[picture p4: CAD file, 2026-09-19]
Hardware/3D Models/Receiver Enclosure/End Cap.3mf
30.0 x 10.0 x 30.0 mm

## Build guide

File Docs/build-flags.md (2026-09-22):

# Firmware build flags

The firmware helpers accept additional compiler definitions with `--define`.
Definitions are compile-time controls; they do not change an already-flashed
board until that board is rebuilt and flashed.

## Common command form

Compile only:

```bash
./Helpers/flash_receiver.sh --define=-DNAME=value
./Helpers/flash_transmitter.sh --define=-DNAME=value
./Helpers/flash_retransmitter.sh --define=-DNAME=value
```

Compile and flash:

```bash
./Helpers/flash_receiver.sh --define=-DNAME=value -f --port <receiver-port>
./Helpers/flash_transmitter.sh --define=-DNAME=value -f --port <transmitter-port>
```

Always restore and flash a production image after a test-only build.

## Receiver flags

| Definition | Default | Purpose |
|---|---:|---|
| `BATTERY_LOW_ASSERT_MS` | `2000` | Continuous comparator-high time before battery-low assertion. |
| `BATTERY_LOW_CLEAR_MS` | `5000` | Continuous comparator-low time before clearing battery-low. |
| `RX_VALIDATE_TEST_PATTERN` | `0` | Enables the legacy deterministic full-universe content check. Keep disabled for arbitrary production DMX. |
| `PRIORITY_STAGING_TIMEOUT_MS` | `4000` | Lifetime of priority fragments and gate metadata while a complete priority universe is reconstructed. |
| `RECEIVER_FAILSAFE_DEFAULT_MODE` | `RECEIVER_FAILSAFE_HOLD` | Receiver boot default: `HOLD`, `BLACKOUT`, or `DISABLE_LINE`. |
| `RECEIVER_FAILSAFE_DEFAULT_TIMEOUT_SECONDS` | `60` | Receiver boot fail-safe timeout. Runtime daemon configuration can override it. |
| `RECEIVER_DIAGNOSTIC_SERIAL` | `0` | Disables physical DMX output and emits complete reconstructed universes as binary `RDX1` records over UART0 at 115200 8N1, including the promoted fragment source MAC. |
| `RECEIVER_DIAGNOSTIC_BAUD` | `115200` | Diagnostic UART baud rate. Use the same rate with the host reader; `460800` is recommended for high-rate diagnostics. |
| `RECEIVER_DIAGNOSTIC_SILENT_CAPTURE` | `0` | Diagnostic-only mode that validates promoted universes in-device and emits compact capture summaries instead of per-universe `RDX1` records. Requires `RECEIVER_DIAGNOSTIC_SERIAL=1`. |

Example receiver test-pattern build:

```bash
./Helpers/flash_receiver.sh --define=-DRX_VALIDATE_TEST_PATTERN=1
```

## Transmitter flags

| Definition | Default | Purpose |
|---|---:|---|
| `WIRELESS_REFRESH_HZ` | `20` | Native/integrated transmitter production refresh rate. The standalone physical retransmitter uses its own 10 Hz default. |
| `WIRELESS_PRIORITY_REFRESH_HZ` | `1` | Priority fragment cadence. |
| `WIRELESS_TX_OVERHEAD_MS` | `27` | Measured normal-frame overhead used by budget pacing. |
| `WIRELESS_TX_DRAIN_TIMEOUT_MS` | `100` | Bound for a stuck ESP-NOW transmit drain. |
| `TRANSMITTER_TELEMETRY_LOGGING` | `0` | Diagnostic text logging. Keep disabled because UART0 carries binary ENTTEC/management traffic. |
| `TRANSMITTER_VERBOSE_LOGGING` | unset | Development logging. Do not enable during normal UART operation. |
| `TRANSMITTER_MANAGEMENT_ONLY` | unset | Disables ordinary DMX fragments while retaining management and priority DMX. |
| `TRANSMITTER_LOCK_BRIDGE` | unset | Locks the runtime role to bridge; daemon mode requests for management-only are rejected. |
| `TRANSMITTER_LOCK_MANAGEMENT_ONLY` | unset | Locks the runtime role to management-only; daemon mode requests for bridge are rejected. |

Management-only images include the optional passive universe observer. No extra
define is required. The observer listens for ordinary retransmitter fragments,
reconstructs complete universes, and serves them through the management protocol;
it does not make the image a normal-DMX source. The host polls at approximately
4 Hz, so the feature is intended for operator feedback rather than precise
monitoring.

The transmitter helper also supports the Wemos D1 Mini/Pro target, which is useful
for bench or enclosure builds that do not use an ESP-01:

```bash
./Helpers/flash_transmitter.sh --d1
./Helpers/flash_transmitter.sh --d1 --lock-management-only -f --port <port>
```

The management-only image is the recommended image for a monitored standalone
retransmitter. It may send management and priority traffic, but it cannot become
the ordinary-DMX authority when statically locked.

The integrated transmitter helper defaults to the normal bridge role. Select
the optional management role with:

```bash
./Helpers/flash_transmitter.sh --management-only
./Helpers/flash_transmitter.sh --lock-bridge
./Helpers/flash_transmitter.sh --lock-management-only
```

## Standalone re-transmitter

The re-transmitter owns UART0/GPIO3 for physical DMX input and must not call
`Serial.begin()` or write diagnostics to that UART. The DMXUART experiment uses
foreground-polled `DMXUART::read()`, sends only normal three-fragment DMX
packets, and waits for its first complete physical universe before transmitting.
It is constructed with no TX pin, which makes the ESP8266 implementation select
`SERIAL_RX_ONLY`; UART0 RX/GPIO3 remains the DMX input and UART0 TX/GPIO1 remains
available for the optional battery comparator.
The retransmitter pauses DMX UART RX while it queues and drains one complete
three-fragment wireless universe, then resumes RX before waiting the configured
wireless interval. This intentionally permits physical-DMX frames to be lost
while protecting wireless transmission.

```bash
./Helpers/flash_retransmitter.sh
./Helpers/flash_retransmitter.sh --menuconfig
./Helpers/flash_retransmitter.sh --channel 1 --universe 1 --rate 10
```

The helper is compile-only unless `-f` is supplied. `--menuconfig` is a small
interactive Bash configuration menu covering channel, universe, wireless rate,
TX drain timeout, and TX overhead. Its defaults are channel `1`, universe `1`,
10 Hz, 100 ms, and 27 ms respectively. Partial-universe acceptance is now the
only retransmitter mode. Command-line flags remain preferred for repeatable
builds; use `--menuconfig` when selecting options interactively.
Relevant definitions are
`RETRANSMITTER_ESPNOW_CHANNEL`, `RETRANSMITTER_UNIVERSE_ID`,
`RETRANSMITTER_WIRELESS_REFRESH_HZ`, `RETRANSMITTER_TX_DRAIN_TIMEOUT_MS`,
`RETRANSMITTER_DIAGNOSTICS`, `RETRANSMITTER_DIAGNOSTIC_BROADCAST`, and
`RETRANSMITTER_TELEMETRY_ONLY`.

Battery-monitoring definitions are `RETRANSMITTER_BATTERY_MONITOR`,
`RETRANSMITTER_BATTERY_PIN`, and `RETRANSMITTER_BATTERY_LOW_ACTIVE_LOW`.
The helper provides `--battery-monitor`, `--no-battery-monitor`, and
`--battery-low-active-high`; `--menuconfig` exposes battery monitoring and
comparator polarity in addition to the timing/radio settings.
The production retransmitter uses an absolute 10 Hz universe deadline. It waits
for a fresh complete physical-DMX frame, sends when the deadline is due, and
rebases one period forward after an overrun instead of compressing catch-up
frames. This prevents stale-frame reuse and avoids adding a second full pacing
interval after physical-DMX capture.
It also invokes Arduino CLI with `--clean` so each flashed image is rebuilt from
the requested compile options rather than relying on a shared sketch cache.
The partial build is exported to `Firmware/ReTransmitter/build/partial`. The helper
prints the selected mode, binary path, and SHA-256 before flashing.

The generic `--define DEFINE` option remains available for test-only or future
compile definitions that are not part of the retransmitter's normal menu.

With no extra flags, the retransmitter helper builds the production 10 Hz image
with retransmitter telemetry enabled and diagnostics/diagnostic broadcasts
disabled. `--production` explicitly selects this mode and is mutually exclusive
with `--telemetry-only`. The telemetry-only image is a test variant: it disables
physical-DMX input and normal fragment transmission while retaining the telemetry
scheduler and management reporting. It must never be deployed as a normal
retransmitter. The `--menuconfig` rate default is also 10 Hz. The retransmitter
accepts valid physical DMX frames from
the pinned library's
minimum callback threshold through 512 slots and zero-fills channels after the
received slot count through channel 512. The helper is:

```bash
./Helpers/flash_retransmitter.sh
```

Malformed frames and nonzero start codes remain rejected by the input library.

The processing cost is negligible because the retransmitter already maintains
and clears a 512-channel destination buffer. Partial operation depends on
DMXUART's minimum channel threshold (`UART_MINCHANS_DMX`, currently 24); frames
below that threshold do not produce a usable callback.

## Fault-injection flags

These flags are defined in the Firmware/Transmitter/receiver test-hook comments and are
intended for isolated reconstruction testing:

| Definition | Target | Purpose |
|---|---|---|
| `TEST_DROP_FRAGMENT_INDEX=N` | transmitter | Omits one normal fragment. |
| `TEST_DUPLICATE_FRAGMENT_INDEX=N` | transmitter | Adds a duplicate normal fragment. |
| `TEST_REORDER_FRAGMENTS` | transmitter | Sends normal fragments in reordered sequence. |
| `TEST_CORRUPT_FRAGMENT_INDEX=N` | transmitter | Corrupts one normal payload for legacy validation builds. |
| `TEST_CORRUPT_BYTE=N` | transmitter | Selects the payload byte to corrupt. |
| `TEST_FORCE_SEQUENCE_START=N` | transmitter | Starts normal sequence numbering at a selected value. |
| `TEST_SEQUENCE_WRAP` | transmitter | Starts near the 32-bit sequence rollover. |
| `TEST_DELAYED_FRAGMENT` | transmitter | Sends a stale delayed fragment after a controlled delay. |
| `TEST_SUPPRESS_DMX_TRANSMISSION` | transmitter | Suppresses normal and priority DMX fragments while retaining management/telemetry. Used for finite fail-safe tests. |
| `TEST_INJECT_MALFORMED` | legacy receiver test sketch | Injects malformed input for isolated validation. |

## Monitor flags

The Arduino Mega monitor uses a library-wide build flag rather than a sketch
local define:

```bash
./Helpers/flash_enttec_dmx_monitor.sh -f --port <monitor-port>
```

The helper passes `-DDMX_USE_PORT1`, placing DMX input on Mega USART1 while USB
Serial remains the command/result interface.

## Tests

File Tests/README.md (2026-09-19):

# Tests and validation sketches

This directory contains Arduino test sketches, hardware monitors, acceptance
plans, and test-specific harnesses. It is separate from the production firmware
under `../Firmware/` and the automated Python suite under
`../Host Software/wireless_dmx_daemon/tests/`.

## Contents

- ESP-NOW basic and universe transmitter/receiver checks.
- Mega DMX controllers and physical-DMX monitors.
- Pico refresh monitoring.
- GPIO and receiver diagnostics.
- Retransmitter end-to-end generation and monitoring.
- Feature test plans and the retransmitter acceptance plan.

Use the helpers in `../Helpers/` to compile these sketches. Read
[`../Docs/testing.md`](../Docs/testing.md) and
[`../Docs/lab-validation.md`](../Docs/lab-validation.md) before connecting
hardware. Live runners can open real serial devices and must only be run after
wiring, firmware images, and ports have been explicitly confirmed.

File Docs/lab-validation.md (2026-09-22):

# Lab validation record

This document records Linux hardware qualifications and is not a required
deployment topology. USB device assignments and monitor wiring are session
specific; receiver identities were discovered from telemetry.

Validated behavior included normal 20 Hz acceptance, priority delivery, hard
gates, receiver removal/reconnection, transmitter reset, daemon restart, PTY
telemetry, priority soak, and receiver `hold`, `blackout`, and
`disable_line` tests.

Fail-safe evidence included a 60-second hold test, a bounded 30-second
blackout test producing a finite all-zero measurement, and a bounded
disable-line test producing zero DMX checks with more than 42 seconds of
no-data. Production transmitter firmware was restored and fresh DMX recovery
passed after each mode.

These results document behavior, not a fixed receiver count, receiver ID set,
USB numbering scheme, or monitor assignment.

## Physical retransmitter qualification

The standalone physical retransmitter has a 10 Hz production target. Its
validated physical-DMX path includes the DMXUART full-frame BREAK correction,
source-frame handling through 512 slots, and receiver-side complete universe
promotion checks. Extended boundary, transition, and long-run testing completed
with matching content and no improper receiver promotion.

The physical retransmitter may be deployed without a management transmitter.
When telemetry/control is required, use a separate transmitter locked to
management-only mode. The management device is optional and must not become a
competing normal-DMX authority. The management-only image also provides an
optional best-effort observed-universe display by listening to retransmitter
fragments and exporting complete snapshots over its host UART. This display is
not a substitute for dedicated Firmware/Receiver/DMX measurement.

The production retransmitter telemetry/control implementation and extended
validation were completed on the `feature/retransmitter-telemetry-control`
branch (commit `e716a05`). Production operation was accepted at approximately
10 Hz with valid reconstructed content, zero post-sync CRC errors, source
mismatches, sequence backtracks, or wireless send failures. Boundary, transition,
and long-soak runs completed with healthy queues and balanced fragments. The
extended matrix recorded 25/27 passing cases; the two failures were Mega
source-result/reporting checks, not retransmission-integrity failures. Treat
those harness results as reporting follow-up if a fully green extended report is
required.

### Post-reflash locate and DMX smoke evidence

The retransmitter was subsequently restored to the pre-input-gating GPIO
allocation: GPIO2 is the locate indicator, while DMX input remains continuously
available. Locate functionality was verified after flashing. A follow-up 30-second
production smoke test then used the Mega source on `/dev/ttyUSB2`, the diagnostic
receiver on `/dev/ttyUSB1` at 460800 baud, and the management transmitter on
`/dev/ttyUSB0`.

The diagnostic receiver captured 356 valid normal-DMX records with zero CRC or
unknown-record errors. Sequences advanced from 12 through 370 and all records
identified source MAC `cc:50:e3:fd:a9:76`. Retransmitter telemetry increased
input frames from 0 to 253 and wireless frames from 0 to 252, while wireless
send failures remained 0. This confirms physical DMX reception and wireless
retransmission after the locate restoration. Battery-monitor support is available
in production builds through `--battery-monitor`; the smoke test did not assert a
battery level.
For wiring, image roles, flash procedures, port safety, deployment, and both
standalone and monitored deployment procedures, see
[`retransmitter-deployment.md`](retransmitter-deployment.md).

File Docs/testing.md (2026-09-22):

# Testing guide

Host validation:

```bash
cd "Host Software/wireless_dmx_daemon"
python3 -m pytest -q
python3 -m py_compile wireless_dmx/**/*.py tests/*.py
```

Firmware validation:

```bash
./Helpers/flash_receiver.sh
./Helpers/flash_transmitter.sh
```

To isolate ESP-01/ESP-01S onboard LED and pin wiring from the production
receiver, use the standalone GPIO diagnostic:

```bash
./Helpers/flash_gpio_blink.sh
./Helpers/flash_gpio_blink.sh -f --port /dev/ttyUSB0
```

This test does not initialize DMX, Wi-Fi, or QuickESPNow. It drives GPIO1 and
GPIO2 together with a 500 ms half-period (one full blink per second).

The integrated receiver locator uses the same GPIO pins for a 15-second default
interval. It is disruptive to DMX output and should only be used with the
receiver disconnected from DMX fixtures.

Hardware tests should discover receiver IDs dynamically and never assume which
receiver is connected to a physical monitor. Use finite Mega monitor commands;
`disable_line` intentionally produces no DMX data and must not cause an
unbounded wait.

Recommended coverage includes normal output, priority/gates, receiver removal
and recovery, transmitter reset, daemon restart, PTY reconnect, and all three
fail-safe modes. For blackout/disable-line testing, establish a normal baseline
before stopping wireless fragments. The test-only transmitter define
`-DTEST_SUPPRESS_DMX_TRANSMISSION` suppresses DMX fragments while preserving
management/telemetry; restore the production transmitter image afterward.

## Raw DMX timeout validation with the Mega monitor

The raw-DMX path can be validated with the existing Arduino Mega DMX monitor
without changing receiver firmware:

1. Build a writable configuration with `[raw_virtual_port] enabled = true`,
   `source_policy = "raw_serial"`, and `timeout_seconds = 1.0`.
2. Start the daemon with that configuration and record the printed raw-DMX PTY.
3. Connect the Mega monitor to the receiver DMX output and establish a baseline
   using a complete constant universe, for example all channels set to `77`.
4. Write a different universe value, such as `99`, to the raw PTY in two parts,
   but stop before 512 bytes are sent.
5. Wait at least 1.2 seconds. The daemon's `raw_serial_timeout_drops` counter
   should increase, and the receiver should continue holding the previous
   complete universe.
6. Send one complete 512-byte universe of `99` and verify that the Mega records
   valid DMX frames with the new value and no mixed or partial universe.
7. Repeat with partial lengths near the boundary (1, 255, 511 bytes), with a
   pause below the timeout to confirm completion still works, and with a pause
   above the timeout to confirm abandonment.
8. Repeat at the intended operating cadence (for example 20 complete bursts per
   second) for a finite 60-second run. Require positive Mega checks, zero
   pattern/content failures, no unexplained no-data gaps, and zero unexpected
   timeout drops during complete-burst operation.

The Mega monitor's `START` command must always use a finite measurement window;
do not wait indefinitely for `disable_line` or a deliberately absent raw burst.
This procedure validates both raw input framing and end-to-end physical DMX
output. The timeout itself is validated by the absence of a partial promotion
and successful recovery on the next complete universe.

## Optional management-only observed-universe validation

The management-only transmitter can display the normal universe broadcast by a
standalone retransmitter. This is an optional operator aid and is not required
for receiver output. Flash the management-only image with:

```bash
./Helpers/flash_transmitter.sh --management-only
```

For a live check, connect the management transmitter to the host and run the
daemon/dashboard in management-only mode while a standalone retransmitter and
production receiver operate on the same ESP-NOW channel. Open the manual
universe view with `u`; it should show the observed universe with source, age,
sequence, and `LIVE` status. Confirm that missing radio traffic eventually shows
`STALE` without changing receiver operation, and that a complete retransmitter
update replaces non-locked displayed channels.

To validate hard-lock behavior, observe a nonzero channel, press `l` until it is
`LOCKED`, and confirm its current value is retained while subsequent
retransmitter updates change other channels. An explicit management edit to the
locked channel must still be accepted and sent as priority traffic. This display
check does not replace a physical DMX monitor; it observes one radio path and is
best-effort.

## Physical-DMX re-transmitter end-to-end setup

The re-transmitter hardware setup uses an Arduino Mega as both the physical DMX
generator and the returned-DMX monitor. The Mega harness is:

```text
Tests/retransmitter_end_to_end/retransmitter_end_to_end.ino
```

Compile it without flashing:

```bash
./Helpers/flash_retransmitter_e2e_mega.sh
```

The detailed topology, separate Mega UART allocation, RS-485 requirements,
partial-universe cases, management-only coexistence cases, and acceptance
criteria are documented in:

```text
Tests/RETRANSMITTER_E2E_TEST_PLAN.md
```

The live runner is deliberately outside the automated suite:

```text
Host Software/wireless_dmx_daemon/tests/run_retransmitter_acceptance.py
```

It must not be invoked until physical wiring and firmware flashing have been
explicitly approved. For the diagnostic receiver pathway, build the receiver with
`RECEIVER_DIAGNOSTIC_SERIAL=1`. This disables `espDMX` and the MAX3485 output;
the receiver instead emits complete `RDX1` binary reconstructed-universe
records on UART0/GPIO1, read through the receiver's USB serial adapter. Use
`RECEIVER_DIAGNOSTIC_BAUD` and the runner's `--receiver-baud` together; for
example, build with `--diagnostic --diagnostic-baud 460800` and run with
`--receiver-baud 460800`. The Mega then only needs to generate physical DMX on
USART1. The live runner uses `--receiver-port` for this diagnostic stream.
Diagnostic records have the format `RDX1`, record type, little-endian frame
sequence, six-byte source MAC, 512 promoted channel bytes, and CRC16. Always
record and review the source MAC when more than one normal-DMX transmitter may
be powered or within radio range.

## Extended physical retransmitter validation

The low-rate/extended runner is:

```text
Host Software/wireless_dmx_daemon/tests/run_retransmitter_extended_validation.py
```

The standalone physical retransmitter production target is 10 Hz. The native
integrated transmitter production target is 20 Hz. The receiver
silent-capture summary enforces the promotion invariant:

```text
promotions == matching
complete_candidates == promotions + rejected_complete
corrupt == rejected_complete
```

Incomplete, malformed, stale, duplicate, and content-invalid universes must
never replace the active receiver universe. The retransmitter source MAC must
be operator-confirmed, not inferred from a host USB programmer.

The production retransmitter image is built with telemetry enabled and runs at
the 10 Hz normal-universe target. For an isolated telemetry scheduler/control
test, use `./Helpers/flash_retransmitter.sh --telemetry-only`; this test image
does not read physical DMX or transmit normal fragments and must be replaced with
`--production` before deployment. The optional management transmitter should be
flashed with `--lock-management-only` so it cannot become a second normal-DMX
authority.

The completed extended run reported 25/27 cases passing. The two non-passing
results were Mega source-result/rate-reporting issues; source reconstruction and
retransmission integrity passed. If a fully green report is required, repair the
harness capture checks and rerun the same 10 Hz acceptance matrix.

## Verified post-reflash smoke test

After restoring the production retransmitter image with GPIO2 returned to its
locate-indicator role, a live smoke test used:

```text
/dev/ttyUSB0  management transmitter
/dev/ttyUSB1  diagnostic receiver, 460800 baud
/dev/ttyUSB2  Mega physical-DMX source
```

The Mega ran the dynamic 512-slot source for 30 seconds. The diagnostic receiver
reported 356 valid normal-DMX records, zero diagnostic CRC errors, zero unknown
record types, and one advancing source MAC (`cc:50:e3:fd:a9:76`). Retransmitter
telemetry showed input frames increasing from 0 to 253 and wireless frames from
0 to 252, with wireless send failures remaining at 0. This is positive evidence
that physical DMX reception and wireless retransmission remained functional after
the locate/GPIO2 restoration and battery-monitor-capable production build.

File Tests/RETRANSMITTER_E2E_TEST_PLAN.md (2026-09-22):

# Re-transmitter end-to-end hardware test plan

This plan is for the physical setup below. It is intentionally separate from
the host unit suite and compile checks. Do not run the live acceptance runner
until the hardware has been wired, firmware has been flashed, and the operator
has confirmed the setup.

## Topology

```text
/dev/ttyUSB0 -> ESP-01 management transmitter
                    management + priority ESP-NOW only

/dev/ttyUSB2 -> Arduino Mega USB command/result port
                    |
                    +-- USART1 TX / pin 18 -> RS-485 driver -> DMX input line
                                                           |
                                                           v
                                                   ESP-01 re-transmitter
                                                   UART0 RX / GPIO3
                                                           |
                                                    normal ESP-NOW DMX
                                                           |
                                                           v
                                                   ESP-01 diagnostic receiver
                                                           |
/dev/ttyUSB1 <- receiver UART0 TX / GPIO1 diagnostic stream

```

The Mega requires one RS-485 interface:

1. A transmit-only interface for generated DMX.

The diagnostic receiver build completely disables physical DMX output and
instead emits complete reconstructed universes as binary `RDX1` records over
its USB serial port. In the verified setup, `/dev/ttyUSB1` is the
logical-universe monitor after the receiver has been flashed with this diagnostic
build. The default diagnostic baud is 115200; use
the same selected baud in the receiver build and acceptance runner. A 460800
baud build is recommended for high-rate diagnostic capture:

```bash
./Helpers/flash_receiver.sh --diagnostic --diagnostic-baud 460800
python Tests/run_retransmitter_acceptance.py ... --receiver-baud 460800
```

Build the diagnostic receiver image with:

```bash
./Helpers/flash_receiver.sh --diagnostic
```

The diagnostic stream is fixed binary records:

```text
RDX1 | record type | little-endian frame sequence | source MAC (6 bytes) |
     | 512 channel bytes | CRC16
```

The receiver USB serial adapter must be configured for the selected diagnostic
baud (460800 is the verified high-rate setup; 115200 is also supported). This is a
logical reconstructed-DMX observation path; the receiver's physical MAX3485
DMX output remains disabled in this image.

Diagnostic records include the ESP-NOW source MAC for the promoted fragment
sequence. This is important when more than one normal-DMX authority may be
within radio range: content validation without source attribution cannot prove
which transmitter produced a promotion.

## Software assets

Mega generator/monitor sketch:

```text
Tests/retransmitter_end_to_end/retransmitter_end_to_end.ino
```

Compile-only helper:

```bash
./Helpers/flash_retransmitter_e2e_mega.sh
```

The helper deliberately has no upload option. Hardware flashing is a separate
operator-controlled step after this plan has been reviewed.

Finite live runner:

```text
Host Software/wireless_dmx_daemon/tests/run_retransmitter_acceptance.py
```

It opens real serial devices only when explicitly invoked with `--tx-port` and
`--mega-port`. It is not part of the automated test suite and must not be run
during software-only validation.

## Mega command protocol

The Mega uses `/dev/ttyUSB1` at 115200 8N1. The diagnostic receiver uses
`/dev/ttyUSB2` at 460800 8N1.

```text
GENERATE CONST <value>
GENERATE RAMP <base>
GENERATE DYNAMIC <base> <change_ms>
GENERATE SHORT <slots> <base>
STOP
START <settle_seconds> <measure_seconds>
STATUS
ABORT
```

The generated DMX is sent through USART1 as an explicit 513-byte DMX frame
(start code plus channels 1 through 512). The dynamic generator changes channel
1 once per requested interval while keeping the remaining channels deterministic;
this avoids manufacturing torn source frames while still exercising changing
data. Reconstructed data is read from the diagnostic receiver's `/dev/ttyUSB2`
binary stream.

The Mega reports finite results such as:

```text
RESULT seconds=30 generator_slots=512 checked=... pass=... fail=... partial=... max_gap=... no_data=...ms
```

The diagnostic receiver provides the returned-DMX observation stream. The Mega
source uses USART1 only to generate physical DMX; it does not itself monitor the
wireless return path in this topology. The diagnostic parser validates complete
512-channel reconstructed records, and for partial generated input expected
channels after the generated slot count are zero.

## Safety and preparation checklist

Before applying power or connecting DMX:

- Confirm `/dev/ttyUSB0`, `/dev/ttyUSB1`, and `/dev/ttyUSB2` identities with
  stable USB properties; do not rely on enumeration order alone.
- Disconnect the re-transmitter USB programmer before connecting physical DMX
  to its UART0/GPIO3 input.
- Keep the re-transmitter RS-485 transceiver receive-only.
- Keep the Mega generator transceiver transmit-only during generated-DMX tests.
- Keep the Mega returned-DMX monitor transceiver receive-only.
- Use separate RS-485 transceivers for the Mega output and Mega monitor input.
- Verify RS-485 A/B polarity, termination, signal reference, and voltage levels.
- Do not enable two RS-485 drivers on the same line.
- Avoid conflicting power sources and observe the receiver board's lack of
  galvanic isolation.
- Disconnect the receiver from fixtures before applying disruptive output or
  locate commands.

## Firmware roles for initial testing

Initial conservative setup:

```text
Management transmitter: TRANSMITTER_LOCK_MANAGEMENT_ONLY
Re-transmitter:         production 10 Hz telemetry build
Receiver:               production receiver firmware
Mega:                   retransmitter_end_to_end sketch
```

Compile commands:

```bash
./Helpers/flash_transmitter.sh --lock-management-only
./Helpers/flash_retransmitter.sh --production --channel 1 --universe 1 --rate 10
./Helpers/flash_receiver.sh
./Helpers/flash_retransmitter_e2e_mega.sh
```

These commands compile only. Flashing the retransmitter itself requires its
ESP8266 programming port; the host management transmitter and diagnostic
receiver use their separate ports.

All ESP-NOW devices must use the same channel and universe settings. The
re-transmitter is the only normal-DMX authority. The management transmitter is
allowed management/control packets and explicit priority traffic only.

The production retransmitter also reports best-effort telemetry: physical-DMX
freshness and slot count, always-enabled input state, locate state, wireless frame
counters, battery state, and control-generation compatibility fields. GPIO2 is
the locate indicator; production input is not remotely gated. Telemetry must
never delay a DMX fragment or create a catch-up burst. Use `--telemetry-only`
only for scheduler/control tests; that image disables physical-DMX input and
normal retransmission.

The verified post-reflash smoke test used the corrected live port mapping
(`/dev/ttyUSB0` management transmitter, `/dev/ttyUSB1` diagnostic receiver at
460800 baud, `/dev/ttyUSB2` Mega source) and recorded 356 valid normal-DMX
diagnostic records, advancing sequences, input frames `0 -> 253`, wireless
frames `0 -> 252`, and zero wireless send failures.

## Test phases

### 1. Wired source baseline

Generate constant values, ramps, and boundary values. Confirm that the Mega
returned-DMX monitor sees the same values after the wireless receiver path.
Check channels 1, 2, 255, 256, 511, and 512 explicitly.

Pass criteria:

- `checked > 0`
- `fail = 0`
- all 512 channels match
- no mixed-frame values

### 2. Partial zero-fill and corruption detection

Build and flash the sole supported partial-universe retransmitter image:

```bash
./Helpers/flash_retransmitter.sh -f --port <retransmitter-programmer>
```

Test practical lengths supported by the pinned input library, including 25,
100, 255, 256, 511, and 512 slots. Confirm channels after the received count
are zero and do not retain values from a previous longer frame.

The pinned `DMXUART` library has a minimum callback threshold, so very
short frames below that threshold are not expected to produce callbacks.

Partial mode accepts callback-complete DMX frames from the library's minimum
slot threshold through 512 slots, copies the completed frame, and zero-fills
the remaining channels. Tests must verify that no tail channel retains data
from a previous longer frame.

The retransmitter callback handoff must be treated as a synchronized operation:
the pinned `DMXUART` library copies every callback-complete frame into a
shared completed buffer before calling the application callback. The
retransmitter snapshots each callback-complete frame into private storage and
zero-fills its unused tail before the foreground handoff. This prevents a
short frame from being paired with stale data from a previous longer frame.

The live runner selects the source length with `--pattern short --slots N` or
the frame-unique changing pattern with `--pattern dynamic-short --slots N`.
Representative commands are:

```bash
# Fixed partial image: channels 1..N must match and N+1..512 must be zero.
python3 Host Software/wireless_dmx_daemon/tests/run_retransmitter_acceptance.py \
  --tx-port /dev/ttyUSB0 --mega-port /dev/ttyUSB2 --receiver-port /dev/ttyUSB1 \
  --pattern short --slots 236 --value 99 --seconds 20

# Frame-unique partial image: detects torn/mixed universes and tail retention.
python3 Host Software/wireless_dmx_daemon/tests/run_retransmitter_acceptance.py \
  --tx-port /dev/ttyUSB0 --mega-port /dev/ttyUSB2 --receiver-port /dev/ttyUSB1 \
  --pattern dynamic-short --slots 236 --value 99 --change-ms 100 --seconds 20 \
  --expected-rate-hz 20 --rate-tolerance-hz 2
```

The production-rate gate requires the measured diagnostic promotion rate to be
at least 18 Hz for a 20 Hz run. The runner also reports sequence gaps and the
maximum/p95 promotion gaps separately, so packet loss is not hidden by an
average rate. Repeat the frame-unique test at the fragment boundaries 25, 235,
236, 237, 255, 256, 257, 471, 472, 473, 511, and 512 slots. A passing run has
zero invalid/torn records, zero nonzero-tail violations, zero sequence
backtracks, zero CRC errors, and no unexpected source MACs.

### 3. Input interruption and recovery

Stop and restart the Mega DMX generator, then reset the re-transmitter. Confirm
the receiver holds the last complete universe during source loss and accepts a
new complete universe after recovery.

### 4. Management-only coexistence

Run the daemon in management-only mode against `/dev/ttyUSB0`. Confirm:

- telemetry discovery works;
- normal retransmitted DMX remains unchanged;
- fail-safe/output controls behave as documented;
- management transmitter absence does not stop normal retransmission;
- daemon/transmitter reconnect does not corrupt the normal universe.

The extended dynamic soak uses:

```bash
python3 Host Software/wireless_dmx_daemon/tests/run_retransmitter_acceptance.py \
  --tx-port /dev/ttyUSB0 --mega-port /dev/ttyUSB2 \
  --receiver-port /dev/ttyUSB1 --receiver-baud 460800 \
  --seconds 900 --pattern dynamic --change-ms 1000
```

The runner samples daemon state once per second but leaves telemetry requests
under service control. With `telemetry_interval_seconds = 10`, the completed
900-second run produced 91 requests and 91 reports, with zero telemetry failures.
It produced 7,991 valid diagnostic normal-universe records and zero invalid
promotions. A diagnostic CRC count before content synchronization may be
nonzero due to startup stream alignment; CRC errors after the first valid
dynamic promotion fail the run.

## Extended retransmitter validation runner

The staged extended validator uses the Mega and diagnostic receiver directly,
resets the receiver before every case, requires exactly one capture
acknowledgement, and stops immediately on a setup/no-data failure. It does not
open `/dev/ttyUSB0`, so it cannot introduce a second normal-DMX authority.

From the repository root, the default command runs only the safe preflight:

```bash
python3 Host Software/wireless_dmx_daemon/tests/run_retransmitter_extended_validation.py
```

Run the phases separately as follows:

```bash
# Thirty-second 236-slot preflight, then thirty-second 512-slot preflight at the
# production 10 Hz retransmission target.
python3 Host Software/wireless_dmx_daemon/tests/run_retransmitter_extended_validation.py --preflight-only

# 24, 25, 100, 235, 236, 237, 255, 256, 257, 471, 472, 473, 511, 512.
python3 Host Software/wireless_dmx_daemon/tests/run_retransmitter_extended_validation.py --matrix-only

# Real source-length transitions, including 512->24 and 24->512.
python3 Host Software/wireless_dmx_daemon/tests/run_retransmitter_extended_validation.py --transitions-only

# 15-minute 512-slot, 10-minute 24-slot, and 10-minute 237-slot soaks.
python3 Host Software/wireless_dmx_daemon/tests/run_retransmitter_extended_validation.py --soaks

# Run the complete staged validation (approximately one hour).
python3 Host Software/wireless_dmx_daemon/tests/run_retransmitter_extended_validation.py --all
```

Use `--mega-port`, `--receiver-port`, and `--receiver-baud` to override the
documented `/dev/ttyUSB1`, `/dev/ttyUSB2`, and 460800 defaults. Each invocation
writes per-case JSON plus `summary.json` and `summary.md` under
`Host Software/wireless_dmx_daemon/runs/retransmitter-extended/<timestamp>/`.

The completed extended validation recorded 25/27 passing cases. Two failures were
Mega source-result/rate-reporting harness issues; they did not indicate invalid
reconstruction, and retransmission integrity passed. A fully green rerun requires
fixing the Mega result-line capture/source-rate checks rather than changing the
retransmitter acceptance criteria.

### 6. Priority and gates

Use the management-only daemon to send a priority universe and gate metadata.
Confirm priority ACKs, locked-channel behavior, open-channel following, and
normal retransmission after priority completion.

The gate distinction is important for a standalone retransmitter:

- `MANAGEMENT_ONLY` is a daemon-side soft gate. It blocks ordinary source frames
  that enter the daemon, but cannot filter normal packets generated independently
  by the physical retransmitter. Its host-side behavior is covered by the service
  tests and must not be treated as receiver-side persistence.
- `LOCKED` is receiver-side hard-gate metadata carried by a priority transaction.
  Test channels on both sides of fragment boundaries, require
  `PRIORITY_COMPLETE_GATE_APPLIED`, verify locked values persist through normal
  retransmitter traffic, then explicitly clear the mask and verify normal output
  recovery.

### 7. Runtime mode and lock behavior

Only after the locked management-only baseline passes:

- test runtime-capable transmitter mode changes;
- test locked bridge rejection of management-only requests;
- test locked management-only rejection of bridge requests.

Never intentionally operate two normal-DMX authorities on the same universe.

## Acceptance evidence

Record for each phase:

- firmware/build commands and commit ID;
- USB device identity mapping;
- ESP-NOW channel and universe;
- Mega command transcript;
- `RESULT` line;
- daemon mode and transmitter-mode response;
- receiver ID and telemetry state;
- intentional interruptions and recovery times;
- photos or wiring notes for RS-485 direction/termination.

Hardware validation must be marked separately from compilation and host tests.

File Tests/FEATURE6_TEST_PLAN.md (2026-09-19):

Feature 6 Test Plan — Receiver Reconstruction + Double Buffering
================================================================
Both test programs compile successfully via the existing scripts:
  ./flash_espnow_tx.sh   # compile-only, no -f (fault hooks DEFAULT OFF)
  ./flash_espnow_rx.sh   # compile-only, no -f

To enable a test hook, pass it with --define (the scripts add it to
build.extra_flags). Multiple hooks can be passed in one invocation:
  ./flash_espnow_tx.sh --define -DTEST_DROP_FRAGMENT_INDEX=2
  ./flash_espnow_rx.sh --define -DTEST_INJECT_MALFORMED
  ./flash_espnow_tx.sh -f --define -DTEST_DELAYED_FRAGMENT   # compile + flash

No FreeRTOS or any RTOS code was introduced. All state is managed with
plain Arduino setup()/loop() and a small, deterministic state machine.

Files involved:
  Tests/espnow_universe_rx/espnow_universe_rx.ino   (receiver under test)
  Tests/espnow_universe_tx/espnow_universe_tx.ino   (transmitter / fault injector)
  Tests/FEATURE6_TEST_PLAN.md (this file)

Conventions used below:
  - "TX setting" is the --define value to add to the TX build (or "none").
  - RX serial output is the source of truth for pass/fail; the 5 s "RX STATS"
    line aggregates the counters.
  - All tests are deterministic unless otherwise noted; re-run if RF is noisy.

## Test 1: normal complete frame
TX setting: none (default).
Expected TX: "TX FRAME seq=N fragments=3", three "TX FRAG" lines, "TX FRAME complete".
Expected RX: three fragments accepted, then "RX COMPLETE seq=N ..." with the
six sample bytes printed. Stats: complete=1, integrityFail=0, hasActiveWirelessFrame=true.
PASS: active sequence advances and stays correct across multiple frames.

## Test 2: dropped middle fragment
TX setting: --define -DTEST_DROP_FRAGMENT_INDEX=1
Expected TX: only fragments 1/3 and 3/3 transmitted (no "TX FRAG ... frag=2/3").
Expected RX: two fragments received for each frame; the incomplete frame is
abandoned by EITHER the 2 s staging timeout OR superseded when the next frame's
fragments arrive — whichever hits first. activeUniverse is NOT changed (the
previous complete frame remains). Stats: abandon (abandonedIncomplete and/or
abandonedTimeout) increments, complete stays 0 (or unchanged if a prior frame
had completed).
PASS: no promotion occurs while a fragment is missing; active universe is stable.

## Test 3: dropped final fragment
TX setting: --define -DTEST_DROP_FRAGMENT_INDEX=2
Expected TX: only fragments 1/3 and 2/3 transmitted (no "TX FRAG ... frag=3/3").
Expected RX: coverage never reaches full (only 472 of 512 bytes covered); the
frame is abandoned (timeout or supersede) each cycle. activeUniverse unchanged.
PASS: a missing final fragment can never produce a false "complete" frame.

## Test 4: duplicate fragment
TX setting: --define -DTEST_DUPLICATE_FRAGMENT_INDEX=1
Expected TX: fragment 2/3 transmitted twice per frame (4 slots, count stays 3).
Expected RX: duplicate counter increments for the repeated fragment; the frame
still completes and promotes exactly once. Stats: dup>=1, complete=1, integrityFail=0.
PASS: duplicates are not double-counted and do not block or corrupt promotion.

## Test 5: reordered fragments
TX setting: --define -DTEST_REORDER_FRAGMENTS
Expected TX: fragments transmitted in order 3/3, 1/3, 2/3.
Expected RX: reconstruction succeeds regardless of arrival order (coverage
bitmap + unique-count are order-independent); "RX COMPLETE" with integrity PASS.
PASS: arrival order does not affect the reconstructed universe.

## Test 6: late stale fragment
TX setting: --define -DTEST_DELAYED_FRAGMENT
Behavior: after each normal frame completes, the TX holds ~2.5 s, then re-sends
one fragment of that (already-active) frame. The 2.5 s hold is deliberately
between the RX STAGING_TIMEOUT_MS (2000) and TRANSMITTER_RESET_RECOVERY_MS (3000)
so the link is still "live" and the late fragment must be classified STALE.
Expected RX: the late fragment is NOT promoted and NOT re-baselined; the
"RX STALE seq=..." line appears (or the fragment is dropped as stale) and
activeUniverse is unchanged. Stats: stale increments.
PASS: a late duplicate of an active frame never regresses the active universe.
NOTE: this exercises the stale branch deterministically; the same branch is also
reached by Test 10 (fast transmitter reset).

## Test 7: corrupted payload
TX setting: --define -DTEST_CORRUPT_FRAGMENT_INDEX=1 --define -DTEST_CORRUPT_BYTE=0
Expected TX: one "TX CORRUPT seq=... frag=2 byte=0 -> 0x.." line per frame.
Expected RX: all 3 fragments arrive and coverage completes, but the full 512-byte
integrity check fails at the corrupted byte; the frame is NOT promoted.
Stats: integrityFail increments, complete does not. activeUniverse remains the
last good frame.
PASS: a corrupt-but-complete frame is detected and rejected (no false promote).

## Test 8: malformed metadata / bounds
TX setting: none.
RX setting: --define -DTEST_INJECT_MALFORMED
Behavior: at startup the receiver builds a structurally-malformed packet
(offset+payload > 512) and feeds it through processPacket() directly.
Expected RX: "RX INJECT: feeding a malformed (overflow) packet to processPacket()",
then the malformed counter increments and staging/active state is unchanged.
PASS: malformed metadata is rejected without touching the buffers.
NOTE: build the RX with the hook (see command above), then run normally.

## Test 9: receiver starts mid-stream
TX setting: none. Start the TX and let it run to a high sequence, THEN power/boot
the RX (or use --define -DTEST_FORCE_SEQUENCE_START=100 on the TX and boot both).
Expected RX: the first complete, integrity-passing frame is accepted regardless
of the (non-zero) sequence; hasActiveWirelessFrame becomes true after promotion.
PASS: no sequence-0 assumption; the receiver locks onto the live stream.

## Test 10: transmitter reset (re-baseline)
TX setting: none. Let the RX accept several frames, then power-cycle the TX so
its sequence restarts at 0.
Expected RX: the new lower-sequence frames are treated as STALE while the link is
still live (silence < 3000 ms). Once the link has been quiet for >= 3000 ms, the
RX logs "RX REBASELINE permit seq=..." and re-baselines — but only commits when a
COMPLETE, integrity-passing frame arrives. activeUniverse never regresses.
Stats: stale may increment first, then rebase increments; complete resumes.
PASS: a restarted transmitter is re-acquired safely without a stale regression.

## Test 11: uint32 sequence rollover
TX setting: --define -DTEST_SEQUENCE_WRAP
Expected TX: sequence starts at 0xFFFFFFFE, then wraps 0xFFFFFFFE -> 0xFFFFFFFF -> 0.
Expected RX: the wrap is treated as forward progression (seqIsNewer uses signed
comparison); frames across the wrap are accepted; older pre-wrap fragments are
stale. No "re-baseline" is triggered by the wrap.
PASS: 0xFFFFFFFF -> 0 does not look like a reset/stale event.

## Test 12: multiple receivers
TX setting: none. Run two RX units (separate ESPs, same channel) simultaneously.
Expected: both independently receive, reconstruct, and promote the same complete
frames without any acknowledgement or per-receiver traffic.
PASS: broadcast scales to multiple receivers; both stay in lockstep with TX.

---
RAM/Flash (receiver, default build): 32,224 / 80,192 bytes RAM (40%),
245,008 / 1,048,576 bytes Flash (23%).
With TEST_INJECT_MALFORMED: 32,400 RAM, 245,200 Flash.
TX default: 29,332 RAM, 243,568 Flash.
TX with TEST_DELAYED_FRAGMENT: 29,436 RAM, 243,696 Flash.
(All compile-verified; hook code is compiled out when the define is absent.)

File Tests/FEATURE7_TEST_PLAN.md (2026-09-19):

# Feature 7 Test Plan — Reliable Wireless Refresh Rate

Goal: find **roughly what wireless refresh rate (Hz) the system can sustain
reliably**, using the real production receiver path and a host-logged metric
stream. "Reliable" = high delivered frame rate with low loss and no pattern
errors.

## What is measured

The **integrated** receiver (`Firmware/Receiver/receiver.ino`, ESP-01) is the unit under
test. It receives the QuickESPNow broadcast, reconstructs + double-buffers the
universe (Feature 6), and drives espDMX physical output. An **Arduino MEGA 2560**
sits on that DMX output as a monitor:

```
Tests/espnow_universe_tx  --(ESP-NOW bcast, paces off WIRELESS_REFRESH_HZ)-->
receiver.ino (ESP-01)  --(MAX3485 DMX, 250k 8N2)-->  MEGA 2560 (DMXSerial RX)
   (pattern: universe[i]=(i+seq)&0xFF)                                        |
                                                                              USB Serial (115200) --> host PC
```

The MEGA counts genuinely-new universes, infers loss from frame-sequence gaps,
and reports a metric line to the host every second. This is the "program" the
user requested.

## Files

* `Tests/dmx_refresh_monitor/dmx_refresh_monitor.ino` — the MEGA monitor (DMXSerial RX).
* `./flash_dmx_monitor.sh` — build/flash for the MEGA (passes `-DDMX_USE_PORT1`).
* `./flash_espnow_tx.sh` — build/flash for the Feature 5/6 TX (set rate via `--define`).
* `Testing/feature7_capture.py` — optional host helper: logs the MEGA stream and summarizes.
* `Testing/FEATURE7_RESULTS.md` — results table to fill in after runs.

## Hardware / wiring

* TX: an ESP8266 running `Tests/espnow_universe_tx`, on channel 1.
* RX: the ESP-01 running `receiver.ino`, on channel 1, with a MAX3485 driving DMX.
* MEGA 2560:
  * DMX data (MAX3485 RO) -> **pin 19 (RX1 / USART1)**.
  * MEGA USB (pins 0/1) -> host PC (telemetry, 115200 8N1).
  * DMXSerial drives its default mode pin 2 to LOW in receiver mode (harmless here).
* Keep TX, RX, and MEGA power stable; note TX<->RX distance/obstacles (RF-dependent).

## Making the rate configurable (the Feature 7 change)

`WIRELESS_REFRESH_HZ` in `Libraries/WirelessDMX/src/wireless_protocol.h` is now
`#ifndef`-guarded (default 1). Only the **TX** paces off it; the RX and MEGA are
rate-independent. Set the rate per run with a build define:

```bash
./flash_espnow_tx.sh --define -DWIRELESS_REFRESH_HZ=N      # compile-only
./flash_espnow_tx.sh -f --define -DWIRELESS_REFRESH_HZ=N    # compile + flash
```

The production default is now 20 Hz, based on the measured reliable RF ceiling.
The setting remains configurable, including experimental builds up to 40 Hz.

The integrated transmitter UART is `115200 8N2`; update host test tools and
lighting software accordingly.

## Building / flashing the monitor

```bash
./flash_dmx_monitor.sh                  # compile-only (MEGA, arduino:avr:mega)
./flash_dmx_monitor.sh -f --port /dev/ttyUSB1   # compile + flash
```

`DMX_USE_PORT1` is passed as a **global** build flag (`build.extra_flags`), not a
sketch `#define`, because the DMXSerial port is chosen inside the library's own
`DMXSerial.cpp` translation unit (verified via verbose build: the flag is on the
`DMXSerial.cpp` compile line). Result: DMX on USART1/pin 19; USB Serial free.
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

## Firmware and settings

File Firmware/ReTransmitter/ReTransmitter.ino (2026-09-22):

/**
 * Dumb physical DMX512 -> ESP-NOW retransmitter.
 * UART0/GPIO3 is owned by DMXUART. Do not call Serial.begin() or log.
 */
#include <Arduino.h>
#include <ESP8266WiFi.h>
#include <QuickEspNow.h>
#include <DMXUART.h>
#include <wireless_protocol.h>

#ifndef RETRANSMITTER_ESPNOW_CHANNEL
#define RETRANSMITTER_ESPNOW_CHANNEL ESPNOW_CHANNEL
#endif
#ifndef RETRANSMITTER_UNIVERSE_ID
#define RETRANSMITTER_UNIVERSE_ID DMX_UNIVERSE_ID
#endif
#ifndef RETRANSMITTER_WIRELESS_REFRESH_HZ
#define RETRANSMITTER_WIRELESS_REFRESH_HZ 10U
#endif
#ifndef RETRANSMITTER_TX_DRAIN_TIMEOUT_MS
#define RETRANSMITTER_TX_DRAIN_TIMEOUT_MS 100UL
#endif
#ifndef RETRANSMITTER_TX_OVERHEAD_MS
#define RETRANSMITTER_TX_OVERHEAD_MS 27UL
#endif
#ifndef RETRANSMITTER_FRAGMENT_SPACING_MS
#define RETRANSMITTER_FRAGMENT_SPACING_MS 15UL
#endif
#ifndef RETRANSMITTER_DIAGNOSTICS
#define RETRANSMITTER_DIAGNOSTICS 0
#endif
#ifndef RETRANSMITTER_DIAGNOSTIC_BROADCAST
#define RETRANSMITTER_DIAGNOSTIC_BROADCAST 0
#endif
#ifndef RETRANSMITTER_DMX_UART
#define RETRANSMITTER_DMX_UART 0
#endif
#ifndef RETRANSMITTER_DMX_RX_PIN
#define RETRANSMITTER_DMX_RX_PIN 3
#endif
#ifndef RETRANSMITTER_DMX_INVERT
#define RETRANSMITTER_DMX_INVERT 0
#endif
#ifndef RETRANSMITTER_DMX_SLOT_STABILITY_FRAMES
#define RETRANSMITTER_DMX_SLOT_STABILITY_FRAMES 3
#endif
#ifndef RETRANSMITTER_LOCATE_PIN
#define RETRANSMITTER_LOCATE_PIN LED_BUILTIN
#endif
#ifndef RETRANSMITTER_LOCATE_ACTIVE_LOW
#define RETRANSMITTER_LOCATE_ACTIVE_LOW 1
#endif
#ifndef RETRANSMITTER_TELEMETRY_PERIOD_MS
#define RETRANSMITTER_TELEMETRY_PERIOD_MS 10000UL
#endif
#ifndef RETRANSMITTER_TELEMETRY_JITTER_MS
#define RETRANSMITTER_TELEMETRY_JITTER_MS 1000UL
#endif
#ifndef RETRANSMITTER_TELEMETRY_ONLY
#define RETRANSMITTER_TELEMETRY_ONLY 0
#endif
#ifndef RETRANSMITTER_BATTERY_MONITOR
#define RETRANSMITTER_BATTERY_MONITOR 0
#endif
#ifndef RETRANSMITTER_BATTERY_PIN
#define RETRANSMITTER_BATTERY_PIN 1
#endif
#ifndef RETRANSMITTER_BATTERY_LOW_ACTIVE_LOW
#define RETRANSMITTER_BATTERY_LOW_ACTIVE_LOW 1
#endif
#if RETRANSMITTER_WIRELESS_REFRESH_HZ == 0
#error RETRANSMITTER_WIRELESS_REFRESH_HZ must be positive
#endif
#if RETRANSMITTER_FRAGMENT_SPACING_MS == 0
#error RETRANSMITTER_FRAGMENT_SPACING_MS must be positive
#endif
#if RETRANSMITTER_FRAGMENT_SPACING_MS * DMX_FRAGMENTS_PER_UNIVERSE >= (1000UL / RETRANSMITTER_WIRELESS_REFRESH_HZ)
#error RETRANSMITTER_FRAGMENT_SPACING_MS leaves no inter-universe guard time
#endif

static volatile bool captureRequested = true;
static uint8_t dmxReadBuffer[DMX_UNIVERSE_SIZE];
static DMXUART* dmxInput = nullptr;
static uint32_t inputFramesReceived = 0;
static uint32_t inputFramesSkipped = 0;
static uint32_t inputSlotMismatches = 0;
static uint16_t learnedInputSlots = 0;
static uint16_t candidateInputSlots = 0;
static uint8_t candidateInputSlotFrames = 0;
static uint32_t inputInvalidStartCodes = 0;
static uint32_t inputInvalidLengths = 0;
static uint8_t g_universe[DMX_UNIVERSE_SIZE];
static uint8_t g_txUniverse[DMX_UNIVERSE_SIZE];
static uint32_t g_frameSequence = 0;
/* A valid universe may remain available after it has been transmitted, but a
 * new wireless cycle must not reuse it until a fresh physical-DMX frame has
 * completed. This matters when a 236-slot source changes to 512 slots: the
 * old universe is intentionally zero-filled after slot 236. */
static bool freshUniverseAvailable = false;
static unsigned long lastInputFrameMs = 0;
static uint32_t wirelessFramesSent = 0;
static uint32_t wirelessSendFailures = 0;
static unsigned long nextTelemetryAt = 0;
static uint32_t telemetrySequence = 0;
static volatile bool telemetryPending = false;
static volatile bool telemetryInFlight = false;
static bool locateActive = false;
static unsigned long locateEndMs = 0;
static unsigned long locateNextPulseMs = 0;
static bool locatePulse = false;
static volatile uint8_t sendConfirmations = 0;
static volatile uint32_t txCallbackSuccess = 0;
static volatile uint32_t txCallbackFailure = 0;
static uint32_t frameCallbackSuccessStart = 0;
static uint32_t frameCallbackFailureStart = 0;
static uint32_t txEnqueueAttempts[DMX_FRAGMENTS_PER_UNIVERSE] = {0};
static uint32_t txEnqueueSuccess[DMX_FRAGMENTS_PER_UNIVERSE] = {0};
static uint32_t txEnqueueFailures[DMX_FRAGMENTS_PER_UNIVERSE] = {0};
static uint32_t txSerializedBusySkips = 0;
static uint32_t txMissedDeadlines = 0;
static uint32_t txCycleOverruns = 0;
#if RETRANSMITTER_DIAGNOSTICS
static unsigned long lastDiagnosticsAt = 0;
static const unsigned long DIAGNOSTICS_INTERVAL_MS = 1000UL;
#endif

/* Diagnostic A/B option: reverse the three-fragment burst without changing
 * packet contents, pacing, or frame sequencing. If the missing fragment
 * follows burst position rather than fragment identity, the loss is temporal
 * (UART/SDK/RF burst interaction) rather than packet-specific. */
#if defined(RETRANSMITTER_REVERSE_FRAGMENT_ORDER)
static const uint8_t txFragmentOrder[DMX_FRAGMENTS_PER_UNIVERSE] = {2, 1, 0};
#else
static const uint8_t txFragmentOrder[DMX_FRAGMENTS_PER_UNIVERSE] = {0, 1, 2};
#endif

/* Diagnostic A/B option: wait for the ESP-NOW send callback before enqueueing
 * the next fragment. This removes the three-packet burst while preserving the
 * same packet format and frame sequence semantics. */
#if defined(RETRANSMITTER_REVERSE_FRAGMENT_ORDER)
#error Do not combine retransmitter fragment-order and serialization diagnostics
#endif
static bool haveUniverse = false;
static unsigned long lastFrameGenerationTime = 0;
static unsigned long nextFrameAt = 0;
static bool frameDeadlineValid = false;
static unsigned long stateAt = 0;
static uint8_t currentFragment = 0;

enum TxState { TX_WAIT_INPUT, TX_IDLE, TX_SENDING, TX_DRAIN };
static TxState txState = TX_WAIT_INPUT;
/* Match the normal transmitter's queue/drain state machine. The requested
 * 20 Hz period includes the measured wireless overhead; DMX RX is paused for
 * the complete queued send and resumed after callbacks or the drain timeout. */
static constexpr unsigned long TX_INTERVAL_MS =
    (1000UL / RETRANSMITTER_WIRELESS_REFRESH_HZ > RETRANSMITTER_TX_OVERHEAD_MS)
        ? (1000UL / RETRANSMITTER_WIRELESS_REFRESH_HZ - RETRANSMITTER_TX_OVERHEAD_MS) : 0UL;
static constexpr unsigned long FRAME_PERIOD_MS =
    1000UL / RETRANSMITTER_WIRELESS_REFRESH_HZ;
static bool dmxRxPaused = false;
struct PendingRetransmitterControl {
    uint8_t data[sizeof(RetransmitterLocatePacket)];
    uint8_t len;
};
static PendingRetransmitterControl pendingControl;
static volatile bool controlPending = false;

static uint8_t readBatteryState(void) {
#if RETRANSMITTER_BATTERY_MONITOR
    const bool comparatorActive = digitalRead(RETRANSMITTER_BATTERY_PIN) ==
        (RETRANSMITTER_BATTERY_LOW_ACTIVE_LOW ? LOW : HIGH);
    return comparatorActive ? 1U : 0U;
#else
    return RETRANSMITTER_BATTERY_UNKNOWN;
#endif
}

static void scheduleRetransmitterTelemetry(unsigned long now, bool initial) {
    const unsigned long jitter = RETRANSMITTER_TELEMETRY_JITTER_MS
        ? (initial ? (ESP.getChipId() % (RETRANSMITTER_TELEMETRY_JITTER_MS + 1UL))
                   : random(RETRANSMITTER_TELEMETRY_JITTER_MS + 1UL)) : 0UL;
    nextTelemetryAt = now + RETRANSMITTER_TELEMETRY_PERIOD_MS + jitter;
}

static void serviceLocate(void) {
    if (!locateActive) return;
    const unsigned long now = millis();
    if ((long)(now - locateEndMs) >= 0) {
        locateActive = false;
        digitalWrite(RETRANSMITTER_LOCATE_PIN,
                     RETRANSMITTER_LOCATE_ACTIVE_LOW ? HIGH : LOW);
        if (dmxInput) {
            dmxInput->resumeRx();
            captureRequested = true;
            freshUniverseAvailable = false;
        }
        return;
    }
    if ((long)(now - locateNextPulseMs) >= 0) {
        locatePulse = !locatePulse;
        const bool on = locatePulse;
        digitalWrite(RETRANSMITTER_LOCATE_PIN,
                     on == (RETRANSMITTER_LOCATE_ACTIVE_LOW != 0) ? LOW : HIGH);
        locateNextPulseMs = now + 500UL;
    }
}

static void processRetransmitterControl(void) {
    if (!controlPending) return;
    uint8_t data[sizeof(pendingControl.data)];
    uint8_t len;
    noInterrupts();
    memcpy(data, pendingControl.data, sizeof(data));
    len = pendingControl.len;
    controlPending = false;
    interrupts();
    if (len == sizeof(RetransmitterLocatePacket)) {
        RetransmitterLocatePacket packet;
        memcpy(&packet, data, sizeof(packet));
        if (packet.magic == DMX_PACKET_MAGIC && packet.protocolVersion == DMX_PROTO_VERSION &&
            packet.packetType == RETRANSMITTER_LOCATE_PACKET_TYPE &&
            packet.universeId == RETRANSMITTER_UNIVERSE_ID &&
            (packet.targetRetransmitterId == 0U || packet.targetRetransmitterId == ESP.getChipId()) &&
            packet.durationSeconds >= 1U && packet.durationSeconds <= 15U) {
            locateActive = true;
            locateEndMs = millis() + (unsigned long)packet.durationSeconds * 1000UL;
            locateNextPulseMs = millis();
            locatePulse = false;
            captureRequested = false;
            freshUniverseAvailable = false;
            if (dmxInput && !dmxRxPaused) dmxInput->pauseRx();
        }
    }
}

static void transmitRetransmitterTelemetry(void) {
    if (locateActive) return;
    if (telemetryInFlight || !quickEspNow.readyToSendData()) return;
    RetransmitterTelemetryPacket packet;
    memset(&packet, 0, sizeof(packet));
    packet.magic = DMX_PACKET_MAGIC;
    packet.protocolVersion = DMX_PROTO_VERSION;
    packet.packetType = RETRANSMITTER_TELEMETRY_PACKET_TYPE;
    packet.universeId = RETRANSMITTER_UNIVERSE_ID;
    packet.retransmitterId = ESP.getChipId();
    WiFi.macAddress(packet.macAddress);
    packet.uptimeSeconds = millis() / 1000UL;
    packet.telemetrySequence = telemetrySequence++;
    packet.inputEnabled = 1U;
    packet.inputSignalActive = lastInputFrameMs && millis() - lastInputFrameMs <= 1500UL;
    packet.batteryState = readBatteryState();
    packet.locateActive = locateActive ? 1U : 0U;
    packet.inputHardwareControlAvailable = 0U;
    packet.learnedInputSlots = learnedInputSlots;
    packet.timeSinceLastInputMs = lastInputFrameMs ? millis() - lastInputFrameMs : 0xFFFFFFFFUL;
    packet.inputFramesReceived = inputFramesReceived;
    packet.inputFramesSkipped = inputFramesSkipped;
    packet.invalidStartCodes = inputInvalidStartCodes;
    packet.invalidLengths = inputInvalidLengths;
    packet.wirelessFrameSequence = g_frameSequence;
    packet.wirelessFramesSent = wirelessFramesSent;
    packet.wirelessSendFailures = wirelessSendFailures;
    packet.missedDeadlines = txMissedDeadlines;
    packet.controlGeneration = 0U;
    if (quickEspNow.sendBcast(reinterpret_cast<const uint8_t*>(&packet), sizeof(packet)) == COMMS_SEND_OK) {
        telemetryInFlight = true;
        scheduleRetransmitterTelemetry(millis(), false);
    } else {
        nextTelemetryAt = millis() + 100UL;
    }
}

static void pollDmxInput(void) {
    if (dmxInput == nullptr || dmxRxPaused) return;

    int startCode = -1;
    const int slots = dmxInput->read(&startCode);
    if (slots <= 0) return;
    if (startCode != 0) {
        inputInvalidStartCodes++;
        return;
    }
    if (slots < UART_MINCHANS_DMX || slots > DMX_UNIVERSE_SIZE) {
        inputInvalidLengths++;
        return;
    }

    if (learnedInputSlots == 0) {
        learnedInputSlots = (uint16_t)slots;
    } else if ((uint16_t)slots != learnedInputSlots) {
        inputSlotMismatches++;
        if (candidateInputSlots == (uint16_t)slots) {
            if (candidateInputSlotFrames < 255) candidateInputSlotFrames++;
        } else {
            candidateInputSlots = (uint16_t)slots;
            candidateInputSlotFrames = 1;
        }
        if (candidateInputSlotFrames >= RETRANSMITTER_DMX_SLOT_STABILITY_FRAMES) {
            learnedInputSlots = candidateInputSlots;
            candidateInputSlots = 0;
            candidateInputSlotFrames = 0;
        } else {
            return;
        }
    } else {
        candidateInputSlots = 0;
        candidateInputSlotFrames = 0;
    }

    if (!captureRequested) {
        inputFramesSkipped++;
        return;
    }

    /* DMXUART owns the ISR-side frame assembly. read() copies the completed,
     * stable frame into dmxReadBuffer in foreground context. */
    memcpy(g_universe, dmxReadBuffer, (size_t)slots);
    memset(g_universe + slots, 0, DMX_UNIVERSE_SIZE - (size_t)slots);
    captureRequested = false;
    inputFramesReceived++;
    lastInputFrameMs = millis();
    haveUniverse = true;
    freshUniverseAvailable = true;
}

static void submitFragment(uint8_t fragmentIndex) {
    const uint16_t offset = static_cast<uint16_t>(fragmentIndex) * DMX_PAYLOAD_SIZE;
    const uint8_t payloadLength = dmx_fragment_payload_length(offset, DMX_UNIVERSE_SIZE);
    uint8_t packetBuffer[DMX_TOTAL_PACKET_SIZE];
    DmxFragmentPacket packet;
    packet.magic = DMX_PACKET_MAGIC;
    packet.protocolVersion = DMX_PROTO_VERSION;
    packet.packetType = DMX_PACKET_TYPE;
    packet.universeId = RETRANSMITTER_UNIVERSE_ID;
    packet.frameSequence = g_frameSequence;
    packet.fragmentIndex = fragmentIndex;
    packet.fragmentCount = DMX_FRAGMENTS_PER_UNIVERSE;
    packet.dataOffset = offset;
    packet.payloadLength = payloadLength;
    memcpy(packetBuffer, &packet, sizeof(packet));
    memcpy(packetBuffer + DMX_HEADER_SIZE, g_txUniverse + offset, payloadLength);
    if (fragmentIndex < DMX_FRAGMENTS_PER_UNIVERSE) txEnqueueAttempts[fragmentIndex]++;
    const comms_send_error_t result = quickEspNow.sendBcast(
        packetBuffer, DMX_HEADER_SIZE + payloadLength);
    if (fragmentIndex < DMX_FRAGMENTS_PER_UNIVERSE) {
        if (result == COMMS_SEND_OK) txEnqueueSuccess[fragmentIndex]++;
        else txEnqueueFailures[fragmentIndex]++;
    }
}

#if RETRANSMITTER_DIAGNOSTICS
static void submitDiagnostics(void) {
    RetransmitterDiagnosticsPacket packet;
    packet.magic = DMX_PACKET_MAGIC;
    packet.protocolVersion = DMX_PROTO_VERSION;
    packet.packetType = RETRANSMITTER_DIAGNOSTICS_PACKET_TYPE;
    packet.universeId = RETRANSMITTER_UNIVERSE_ID;
    packet.frameSequence = g_frameSequence;
    packet.inputFramesReceived = inputFramesReceived;
    for (uint8_t i = 0; i < DMX_FRAGMENTS_PER_UNIVERSE; i++) {
        packet.enqueueAttempts[i] = txEnqueueAttempts[i];
        packet.enqueueSuccess[i] = txEnqueueSuccess[i];
        packet.enqueueFailures[i] = txEnqueueFailures[i];
    }
    packet.callbackSuccess = txCallbackSuccess;
    packet.callbackFailure = txCallbackFailure;
    packet.inputFramesSkipped = inputFramesSkipped;
    packet.inputSlotMismatches = inputSlotMismatches;
    packet.learnedInputSlots = learnedInputSlots;
    packet.serializedBusySkips = txSerializedBusySkips;
    packet.missedDeadlines = txMissedDeadlines;
    packet.cycleOverruns = txCycleOverruns;
#if RETRANSMITTER_DIAGNOSTIC_BROADCAST
    quickEspNow.sendBcast(reinterpret_cast<const uint8_t*>(&packet), sizeof(packet));
#endif
}
#endif

void setup(void) {
    /* tx_pin=-1 is intentional. On ESP8266 DMXUART selects
     * SerialMode::SERIAL_RX_ONLY, so UART0 RX/GPIO3 remains DMX input while
     * UART0 TX/GPIO1 is available for the optional battery comparator. */
    static DMXUART input(
        RETRANSMITTER_DMX_UART, dmxReadBuffer, -1, -1,
        RETRANSMITTER_DMX_RX_PIN, RETRANSMITTER_DMX_INVERT, false);
    dmxInput = &input;
#if RETRANSMITTER_BATTERY_MONITOR
    pinMode(RETRANSMITTER_BATTERY_PIN, INPUT);
#endif
    pinMode(RETRANSMITTER_LOCATE_PIN, OUTPUT);
    digitalWrite(RETRANSMITTER_LOCATE_PIN, RETRANSMITTER_LOCATE_ACTIVE_LOW ? HIGH : LOW);
    WiFi.mode(WIFI_STA);
    WiFi.disconnect(false);
    /* Use asynchronous QuickESPNow. Fragment serialization is enforced by
     * the library's packet-aware queue/in-flight state, not by the sketch's
     * global and untagged send callback. */
    if (!quickEspNow.begin(RETRANSMITTER_ESPNOW_CHANNEL, WIFI_IF_STA, false)) {
        while (true) delay(10);
    }
    quickEspNow.onDataSent([](uint8_t*, uint8_t status) {
        if (telemetryInFlight) {
            telemetryInFlight = false;
        } else {
            if (sendConfirmations < 255) sendConfirmations++;
            if (status == ESP_NOW_SEND_SUCCESS) txCallbackSuccess++;
            else txCallbackFailure++;
        }
    });
    quickEspNow.onDataRcvd([](uint8_t*, uint8_t* data, uint8_t len, signed int, bool) {
        if (len == sizeof(RetransmitterLocatePacket)) {
            noInterrupts();
            memcpy(pendingControl.data, data, len);
            pendingControl.len = len;
            controlPending = true;
            interrupts();
        }
    });
    scheduleRetransmitterTelemetry(millis(), true);
}

void loop(void) {
    const unsigned long now = millis();
    processRetransmitterControl();
    serviceLocate();
    if ((long)(now - nextTelemetryAt) >= 0) telemetryPending = true;
    if (telemetryPending && !telemetryInFlight && txState != TX_SENDING && txState != TX_DRAIN &&
        quickEspNow.readyToSendData()) {
        transmitRetransmitterTelemetry();
        telemetryPending = false;
    }
    if (telemetryInFlight) return;
#if RETRANSMITTER_TELEMETRY_ONLY
    return;
#else
    if (locateActive) return;
    pollDmxInput();
#if RETRANSMITTER_DIAGNOSTICS && RETRANSMITTER_DIAGNOSTIC_BROADCAST
    if (txState == TX_IDLE &&
        now - lastFrameGenerationTime < TX_INTERVAL_MS &&
        quickEspNow.readyForSerializedSend() &&
        now - lastDiagnosticsAt >= DIAGNOSTICS_INTERVAL_MS) {
        lastDiagnosticsAt = now;
        submitDiagnostics();
        return;
    }
#endif
    if (!haveUniverse) {
        txState = TX_WAIT_INPUT;
        return;
    }
    if (txState == TX_WAIT_INPUT) {
        if (!freshUniverseAvailable) return;
        freshUniverseAvailable = false;
        if (!frameDeadlineValid) {
            nextFrameAt = now;
            frameDeadlineValid = true;
        }
        lastFrameGenerationTime = now;
        txState = TX_IDLE;
    }
    switch (txState) {
        case TX_IDLE:
            if ((long)(now - nextFrameAt) >= 0) {
                memcpy(g_txUniverse, g_universe, sizeof(g_txUniverse));
                /* The current universe is latched above. Capture exactly one
                 * subsequent physical-DMX frame for the next wireless cycle. */
                captureRequested = false;
                dmxRxPaused = dmxInput->pauseRx();
                if (!dmxRxPaused) {
                    captureRequested = true;
                    txState = TX_IDLE;
                    break;
                }
                currentFragment = 0;
                sendConfirmations = 0;
                frameCallbackSuccessStart = txCallbackSuccess;
                frameCallbackFailureStart = txCallbackFailure;
                stateAt = now;
                nextFrameAt += FRAME_PERIOD_MS;
                /* A long send/capture stall must not cause an immediate burst
                 * of catch-up universes. Rebase to one period from now. */
                if ((long)(now - nextFrameAt) >= 0) nextFrameAt = now + FRAME_PERIOD_MS;
                txState = TX_SENDING;
            }
            break;
        case TX_SENDING:
            if (currentFragment < DMX_FRAGMENTS_PER_UNIVERSE) {
                /* Queue each fragment once. QuickESPNow serializes these
                 * queued sends while DMXUART RX remains paused. */
                submitFragment(txFragmentOrder[currentFragment++]);
            } else {
                stateAt = now;
                txState = TX_DRAIN;
            }
            break;
        case TX_DRAIN:
            if (sendConfirmations >= DMX_FRAGMENTS_PER_UNIVERSE ||
                now - stateAt >= RETRANSMITTER_TX_DRAIN_TIMEOUT_MS) {
                if (dmxRxPaused) {
                    dmxInput->resumeRx();
                    dmxRxPaused = false;
                }
                captureRequested = true;
                const uint32_t frameSuccesses = txCallbackSuccess - frameCallbackSuccessStart;
                const uint32_t frameFailures = txCallbackFailure - frameCallbackFailureStart;
                if (frameSuccesses >= DMX_FRAGMENTS_PER_UNIVERSE && frameFailures == 0U) {
                    if (wirelessFramesSent < 0xFFFFFFFFUL) wirelessFramesSent++;
                } else if (frameFailures > 0U || frameSuccesses < DMX_FRAGMENTS_PER_UNIVERSE) {
                    if (wirelessSendFailures < 0xFFFFFFFFUL) wirelessSendFailures++;
                }
                g_frameSequence++;
                /* Wait for a complete fresh physical-DMX frame before the
                 * next burst. Elapsed time alone is not a valid boundary for
                 * a full 512-slot frame. */
                txState = TX_WAIT_INPUT;
            }
            break;
        case TX_WAIT_INPUT:
            break;
    }
#endif
}

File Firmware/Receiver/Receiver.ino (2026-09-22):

/**
 * Integrated DMX Now Receiver (QuickESPNow RX -> DMX output)
 *
 * Combines the two previously-verified halves into one sketch:
 *   - QuickESPNow broadcast reception + Feature 6 reconstruction/double
 *     buffering (from tests/espnow_universe_rx), with all Serial logging
 *     removed (UART0 is owned by espDMX once dmxA.begin() runs).
 *   - espDMX physical output on UART0/GPIO1 + MAX3485 driver-enable control
 *     (from the original receiver.ino).
 *
 * Data path:
 *   QuickESPNow fragment (ROM timer callback)
 *     -> bounded SPSC handoff ring
 *     -> loop(): validate, assemble into staging, wrap-safe sequence check
 *     -> on COMPLETE + configured validation: pointer-swap promote to active
 *     -> normal build: dmxA.setChans(active) and espDMX self-refreshes output
 *     -> diagnostic build: emit the active universe over UART0 instead
 *   - Low-rate ReceiverTelemetryPacket broadcast with deterministic phase and
 *     bounded retry backoff so multiple receivers do not transmit together.
 *
 * MAX3485 driver enable (GPIO2 via inverting 2N2222):
 *   GPIO2 HIGH -> transistor ON  -> DE LOW  -> DMX output DISABLED
 *   GPIO2 LOW  -> transistor OFF -> DE HIGH -> DMX output ENABLED
 *   Kept disabled during boot/init; enabled once after safe init and left on.
 *
 * Define RECEIVER_DIAGNOSTIC_SERIAL for a test image that completely disables
 * physical DMX output and emits binary promoted-universe records on UART0.
 * This is intentionally not a text log: a complete 512-byte record fits within
 * the 115200-baud diagnostic bandwidth at the validated wireless rates.
 */

#include <Arduino.h>
#include <ESP8266WiFi.h>
#include <QuickEspNow.h>

/* Single canonical protocol definition shared with the transmitter. */
#include <wireless_protocol.h>

#include <espDMX.h>

/* --------------------------------------------------------------------------
 * Receiver pins (fixed hardware allocation)
 * -------------------------------------------------------------------------- */
static const int PIN_DMX_DATA    = 1; // GPIO1 / UART0 TX -> DMX data / MAX3485 DI
static const int PIN_DMX_ENABLE  = 2; // GPIO2 -> MAX3485 DE via inverting 2N2222
static const int PIN_BATTERY_LOW = 3; // GPIO3 -> LOW when battery is low

/* --------------------------------------------------------------------------
 * Reconstruction configuration
 * -------------------------------------------------------------------------- */
/* Abandon a partially assembled staging frame after this much silence. */
static const unsigned long STAGING_TIMEOUT_MS = 2000UL;

/* Permit an "older" sequence to establish a new baseline only after the
 * wireless link has had no accepted fragment for this long (transmitter
 * restarted). Chosen as 3x the 1 Hz refresh period so a live link never
 * falsely re-baselines. Wrap-safe via millis(). */
static const unsigned long TRANSMITTER_RESET_RECOVERY_MS = 3000UL;

/* Telemetry is intentionally low priority and approximately 4-5 seconds apart.
 * The per-receiver phase and per-cycle jitter spread simultaneous receivers. */
#ifndef TELEMETRY_PERIOD_MS
#define TELEMETRY_PERIOD_MS 4000UL
#endif
#ifndef TELEMETRY_JITTER_MS
#define TELEMETRY_JITTER_MS 1000UL
#endif
#ifndef TELEMETRY_RETRY_BACKOFF_MS
#define TELEMETRY_RETRY_BACKOFF_MS 250UL
#endif
#define TELEMETRY_FIRMWARE_VERSION 2U

/* Battery comparator filtering.  Override either value with a compiler
 * definition when a different hardware debounce period is required. */
#ifndef BATTERY_LOW_ASSERT_MS
#define BATTERY_LOW_ASSERT_MS 2000UL
#endif
#ifndef BATTERY_LOW_CLEAR_MS
#define BATTERY_LOW_CLEAR_MS 5000UL
#endif
#ifndef RECEIVER_FAILSAFE_DEFAULT_MODE
#define RECEIVER_FAILSAFE_DEFAULT_MODE RECEIVER_FAILSAFE_HOLD
#endif
#ifndef RECEIVER_FAILSAFE_DEFAULT_TIMEOUT_SECONDS
#define RECEIVER_FAILSAFE_DEFAULT_TIMEOUT_SECONDS 60U
#endif

/* Feature 5 used a deterministic channel pattern to prove fragment assembly.
 * Production DMX content is intentionally arbitrary, so that content check is
 * disabled by default. The structural checks below (wire format, canonical
 * tiles, no overlaps, every expected fragment, and complete 512-byte coverage)
 * remain mandatory in every build. Enable only for legacy Feature 5 tests:
 *   ./flash_receiver.sh --define -DRX_VALIDATE_TEST_PATTERN=1
 */
#ifndef RX_VALIDATE_TEST_PATTERN
#define RX_VALIDATE_TEST_PATTERN 0
#endif
#ifndef RECEIVER_DIAGNOSTIC_SERIAL
#define RECEIVER_DIAGNOSTIC_SERIAL 0
#endif
#ifndef RECEIVER_DIAGNOSTIC_SILENT_CAPTURE
#define RECEIVER_DIAGNOSTIC_SILENT_CAPTURE 0
#endif
#if RECEIVER_DIAGNOSTIC_SILENT_CAPTURE && !RECEIVER_DIAGNOSTIC_SERIAL
#error RECEIVER_DIAGNOSTIC_SILENT_CAPTURE requires RECEIVER_DIAGNOSTIC_SERIAL
#endif
#ifndef RECEIVER_DIAGNOSTIC_BAUD
#define RECEIVER_DIAGNOSTIC_BAUD 115200UL
#endif
#if RECEIVER_DIAGNOSTIC_SERIAL && RECEIVER_DIAGNOSTIC_BAUD < 115200UL
#error RECEIVER_DIAGNOSTIC_BAUD must be at least 115200
#endif

#if RECEIVER_DIAGNOSTIC_SERIAL
#define RECEIVER_DIAGNOSTIC_MAGIC_0 'R'
#define RECEIVER_DIAGNOSTIC_MAGIC_1 'D'
#define RECEIVER_DIAGNOSTIC_MAGIC_2 'X'
#define RECEIVER_DIAGNOSTIC_MAGIC_3 '1'
#define RECEIVER_DIAGNOSTIC_RECORD_NORMAL 1U
#define RECEIVER_DIAGNOSTIC_RECORD_PRIORITY 2U
#endif

/* Bounded callback->loop handoff ring. One more than QuickESPNow's own RX
 * queue depth (ESPNOW_QUEUE_SIZE = 3), so a tight 3-fragment burst is never
 * dropped by our own architecture. Static, bounded, no dynamic allocation. */
/* Priority delivery can arrive as a three-fragment burst while normal traffic
 * is already in the callback handoff. Leave headroom so a timing variation in
 * loop() cannot discard the targeted priority fragments. */
static const uint8_t RX_RING_SIZE = 16;
static const uint8_t RX_SLOT_MAX  = ESPNOW_MAX_MESSAGE_LENGTH; /* 255 */

/* --------------------------------------------------------------------------
 * Universe storage: exactly two 512-byte buffers, promoted by pointer swap.
 * -------------------------------------------------------------------------- */
static uint8_t universeBufferA[DMX_UNIVERSE_SIZE];
static uint8_t universeBufferB[DMX_UNIVERSE_SIZE];

static uint8_t* stagingUniverse = universeBufferA; /* frame being assembled  */
static uint8_t* activeUniverse  = universeBufferB; /* last complete universe */
static uint8_t stagingSourceMac[6] = {0};
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

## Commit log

2026-08-26 Testing RX buffering and fault tolerance
    [espnow_universe_rx.ino, espnow_universe_tx.ino]
2026-09-02 22Hz verification
2026-09-02 Telemetry and battery integration testing
2026-09-09 Fixed receiver telemetry failures on reset
    [app.py, config.py, config_editor.py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]
2026-09-09 Taking a break from priority packets, intermittent airtime failures seem to be causing issues
    [app.py, models.py, run_30min_acceptance.py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]
2026-09-09 Stabilize targeted priority delivery and retries
    [app.py, test_service.py]
2026-09-09 Added PCB files
2026-09-09 Document receiver schematic
2026-09-10 Complete Feature 13 fail-safe refinement
    [app.py, config.py, config_editor.py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]
2026-09-11 Fix receiver locate control and extend default duration
    [app.py, dashboard.py, gpio_blink.ino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]
2026-09-12 Synchronize retransmitter partial frame handoff
2026-09-13 Snapshot accepted DMX frames in ISR-safe handoff
2026-09-16 Checkpoint reliable 512-slot retransmission
2026-09-17 Fix settings editor input and command help
    [dashboard.py, test_dashboard.py]
2026-09-19 Reorganize project for first release
    [Device Body - Recessed Window.3mf, End Cap.3mf, Insert Retainer.3mf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]
2026-09-21 Add retransmitter receiver control and battery monitoring
